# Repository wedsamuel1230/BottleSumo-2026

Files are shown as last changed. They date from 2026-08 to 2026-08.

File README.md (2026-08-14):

# BottleSumo 2026



Hardware, PCB, 3D model, and firmware files for the BottleSumo robot.

## Continuous build

Every pushed commit and pull request runs the Arduino CLI build workflow. The
workflow installs Arduino CLI 1.4.1 and Arduino-ESP32 3.3.8, then compiles the
firmware programs for the planned ESP32-S3-DEVKITC-1-N32R16 board:

```text
esp32:esp32:esp32s3-octal:FlashSize=32M
```

The badge above shows the latest GitHub Actions result. A passing compile only
proves that the sketch builds for the selected toolchain and memory interface;
it does not prove motor direction, sensor readings, FG pulse levels, or other
physical behavior.

The current hardware note assigns the two motor FG inputs to `GPIO9` and
`GPIO12`; the supplied motor reference states 9 FG square-wave pulses per
motor revolution. Electrical level and motor-to-pin assignment still require
bench verification.

The CI workflow installs the versioned candidate sensor libraries listed in
[`ci/arduino-libraries.txt`](ci/arduino-libraries.txt) before compiling every
Arduino sketch under `firmware/`. Arduino CLI resolves installed libraries when
it sees an `#include`, but it does not download an arbitrary missing library
from the registry automatically.

## Documentation

Use the [documentation hub](docs/README.md) to navigate the competition,
hardware, CI, and image references.

## Firmware

The current Arduino sketch is in
[`firmware/movement_test/movement_test.ino`](firmware/movement_test/movement_test.ino).
The pin audit in the board reference must be resolved before applying this
movement test to the assembled v2 PCB.

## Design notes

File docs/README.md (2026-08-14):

# BottleSumo documentation

Use this page as the documentation index. Documents are grouped by the task
they support, and image assets are kept in separate folders so the reference
pages stay easy to scan.

## Competition

- [2026 table-sumo rules](competition/table-sumo-rules-2026.md) - neutral project transcription of the attached Rev.0 rules document.
- [Sensor and strategy design v1](competition/table-sumo-design-v1.md) - research and design proposal with its approval boundary.
- [Design evidence ledger](competition/table-sumo-evidence-ledger.md) - source and evidence register for the design proposal.

## Hardware

- [ESP32-S3-DEVKITC-1-N32R16 pinout](hardware/esp32-s3-devkitc-1-n32r16-pinout.md) - board, GPIO, motor FG, LED, and firmware audit.
- [24GP-2430 motor reference](hardware/motor-24gp-2430-reference.md) - motor listing values, FG notes, and wiring cautions.

## CI and development

- [Arduino CI review](ci/arduino-ci-review.md) - validation gates and residual hardware risk.
- [Arduino sensor library matrix](ci/arduino-libraries.md) - pinned candidate library names and versions.

## Images

### Competition

- [Arena layout](images/competition/arena-layout.png)
- [Bottle dimensions](images/competition/bottle-dimensions.png)
- [Intentional-push ruling](images/competition/intentional-push-ruling.png)

### Motor

- [64:1 performance table](images/motor/motor-24gp-2430-64-to-1-specification.png)
- [Motor dimensions](images/motor/motor-24gp-2430-dimensions.png)
- [FG pulse description](images/motor/motor-24gp-2430-fg-pulse-description.png)
- [Motor wiring and FG](images/motor/motor-24gp-2430-wire-and-fg.png)

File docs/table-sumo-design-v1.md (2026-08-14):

# Table-Sumo Robot: Sensor and Strategy Design v1

Status: Phases 1-3 design review; no implementation authorization yet
Date: 2026-08-14
MCU: ESP32-S3, one controller
Baseline sensor set: 5 VL53L0X-class ToF heads, 4 analog QRE1113 heads

## Approval boundary

This document completes the research and design proposal only. It does not
authorize firmware, wiring changes, PCB changes, or a real-robot test. Phase 4
starts only after the operator approves the Phase 2 and Phase 3 decisions below.

The competition facts supplied in the task, and the repository rules digest in
`docs/rules.md`, are the controlling 2026 rules. External BottleSumo and sumo
sources are used for engineering context only; they do not override the local
rules.

## 1. Phase 1: research

### 1.1 Evidence boundary

The following are direct facts from the supplied rules, the repository, or the
listed device documentation:

- The senior arena can be two offset boards, so the walkable surface can be
  non-convex. The bottle lies somewhere on the joint line. [R1]
- A table edge is detected by the surface disappearing. A tape seam is a
  different event and is not a safe fixed threshold. [R1]
- VL53L0X devices power up at address `0x29`; XSHUT sequencing is required to
  assign addresses. [S2, S3]
- The VL53L0X carrier documentation lists a nominal 25 deg FoV, up to 2 m
  nominal range, 20 mA typical active current, 40 mA peak current, and 400 kHz
  I2C operation. Effective range depends on target and environment; use the
  task's approximately 1.2 m usable-indoor planning value until bench data
  replaces it. [R2, S3]
- The VL53L1X has a programmable ROI, typical 27 deg FoV, short mode around
  1.3 m, and up to 50 Hz short-mode sampling on the cited carrier. [S4]
- ESP32-S3 has two I2C interfaces, two 12-bit SAR ADCs, and ADC2 cannot be used
  with Wi-Fi simultaneously. GPIO0, GPIO3, GPIO45, and GPIO46 are strapping
  pins. [S5]
- The QRE1113 is a 940 nm IR LED plus phototransistor. Its datasheet example
  uses a 1 mm reflector distance; its response varies strongly with distance,
  reflectance, forward current, and ambient conditions. [S6]
- A prior BottleSumo ruleset explicitly defines intentional pushing as contact
  through a sensor-equipped side without contact with the other robot, and
  requires three-second survival. It is useful context, but the supplied 2026
  rules remain authoritative. [S7]

Engineering inferences are labeled as such below. No claim in this document is
physical proof for this robot.

### 1.2 ToF count trade-off: 3 vs 4 vs 5

For a 25 deg full FoV, the nominal transverse footprint at range `d` is:

`width(d) = 2 * d * tan(12.5 deg) = 0.443 * d`

Approximate footprint widths are 13.3 cm at 30 cm, 22.2 cm at 50 cm, 44.3 cm
at 1 m, and 53.2 cm at 1.2 m. Therefore one sensor cannot cover a 75 cm board
width at its practical VL53L0X range. The robot needs motion and a search
pattern; more sensors improve local angular coverage, not whole-arena vision.

| Count | Useful arrangement | Benefit | Cost and blind-zone risk |
|---|---|---|---|
| 3 | Front left, center, right | Lowest GPIO, power, and polling cost; enough for coarse centering | A narrow bottle can fall between beams; one failed head removes a large part of the front arc; little height/profile redundancy |
| 4 | Four contiguous front headings, or two front plus two rear | Better width estimate and some rear recovery awareness | No spare head for a second beam height; four one-shot readings increase stale-data age; two-front/two-rear weakens front lock-on |
| 5 | Three low front heads plus two mid-height outer heads | Contiguous front arc, fallen-bottle coverage, a second height for a tall opponent, and one-head fault tolerance | Five XSHUT lines, about 100 mA typical ToF current, more optical crosstalk testing, and a longer round-robin schedule |

Recommendation: use 5 heads if the actual ESP32-S3 board exposes the proposed
GPIOs and the mechanical bracket fits. A 4-head build is the fallback. Do not
choose 5 merely to claim long-range arena coverage; the search motion is still
mandatory.

Polling cost is dominated by the measurement budget, not the short I2C register
transactions. With a 33 ms budget and a conservative non-overlapping optical
schedule, one bus carrying `n` heads needs approximately `33*n` ms for a
complete fresh set, before bus overhead. A split of 3+2 heads therefore has a
worst bus schedule of about 99 ms, or roughly 10 Hz for the slow bus; a 2+2
four-head split is about 66 ms, or 15 Hz. A single global five-head optical
schedule is about 165 ms, or 6 Hz. The per-head measurement cadence can be
staggered, but the fusion layer must use the age of the oldest required sample,
not the nominal 30 Hz headline. At 400 kHz, the I2C start/status/range reads
are normally a few milliseconds or less and should be measured rather than
assumed. The two ESP32-S3 buses reduce transaction contention, but only a
physical crosstalk test permits overlapping exposures.

Each head adds one XSHUT GPIO and its power/ground branch. SDA and SCL remain
shared per bus. The incremental resource count is therefore approximately:

| Count | XSHUT GPIOs | I2C bus pins | Typical active ToF current | Conservative fresh-set schedule |
|---:|---:|---:|---:|---:|
| 3 | 3 | 2 or 4 | 60 mA | 66-99 ms depending on split |
| 4 | 4 | 4 if split 2+2 | 80 mA | about 66 ms |
| 5 | 5 | 4 if split 3+2 | 100 mA | about 99 ms split, 165 ms globally |

Coverage blind zones have two distinct causes. For heading separation `delta`
and a 25 deg FoV, the nominal angular gap is
`max(0, delta - 25 deg)`, with an approximate transverse gap
`2*d*tan(gap/2)` at range `d`. A 5 deg gap is about 4.4 cm at 0.5 m and
8.7 cm at 1 m; a 20 deg gap is about 17.6 cm and 35.3 cm. The proposed low
row uses 25 deg spacing, so it has no nominal angular gap, but a small bottle
can still be missed because of reflectance, target height, occlusion, and
non-overlap at the edges of real sensor response. Three heads have no spare
height or fault tolerance. Four heads can widen the same-height arc or add
rear awareness, but cannot provide both the low-row bottle coverage and the
mid-row opponent coverage without compromise. Five heads buy height/profile
redundancy and a wider arc at the cost of the schedule above.

### 1.3 ToF mounting geometry

The recommended front geometry is a 95 deg nominal front arc:

- `T0` low-left: optical center 70 mm above the table plane, 55 mm left of the
  robot centerline, yaw -25 deg from the marked front normal.
- `T1` low-center: optical center 70 mm above the table plane, centerline, yaw
  0 deg.
- `T2` low-right: optical center 70 mm above the table plane, 55 mm right of
  the centerline, yaw +25 deg.
- `T3` mid-left: optical center 130 mm above the table plane, 90 mm left of
  the centerline, yaw -35 deg.
- `T4` mid-right: optical center 130 mm above the table plane, 90 mm right of
  the centerline, yaw +35 deg.

The low trio covers the central arc with contiguous nominal 25 deg cones; real
module response may add or remove useful overlap. It is the primary detector
for a bottle lying on its side. The two outer heads extend
the arc and give a second height for an opponent with a taller front. The
low-center head must remain the authoritative approach head; the mid heads
must never be the only evidence used to attack a fallen bottle.

Mounting requirements:

- Measure every height from the laminate surface to the optical window center,
  not from the PCB or chassis.
- Keep the low beam at 65-75 mm. A horizontal bottle with an approximately
  100 mm high profile can intersect that beam; a 130 mm-only design could pass
  above it.
- Keep all heads square to their intended yaw. Do not use a common tilted
  bracket unless the actual pitch is measured and included in calibration.
- Use matte-black, non-glossy dividers or short hoods between adjacent windows.
  They must not intrude into the nominal 25 deg cones. Separate emitters
  physically and avoid pointing adjacent heads directly at each other.
- Do not start two overlapping optical exposures at the same time until a
  bench crosstalk test proves it safe. Two I2C buses reduce bus transaction
  contention; they do not automatically remove optical interference.
- Use the latest timestamp with each range. A stale or invalid range is not a
  target lock and cannot suppress the edge reflex.

VL53L1X upgrade decision: it is worth considering only if the operator has to
  buy new heads. Its longer range, ROI, and short/medium/long distance modes
  are useful for reducing false returns and narrowing a front beam, but the
  bottle is local and the arena still exceeds one sensor footprint. Replacing
  working VL53L0X heads is not the first priority. The upgrade also changes
  library/API and electrical validation risk. Baseline recommendation: keep
  VL53L0X-class heads for the first hardware gate; choose VL53L1X for a new
  build only if the price and driver support are acceptable and the ROI is
  needed after bench tests.

### 1.4 Bottle versus opponent

ToF-only discrimination is probabilistic, not a rule-grade identification:

- Motion: a bottle should remain fixed in world coordinates until pushed; an
  opponent can change range or bearing independently of the robot's commanded
  motion. This is useful only over several samples and is weak if the opponent
  pauses or the robot has no wheel feedback.
- Width: adjacent low heads returning similar distances suggest a broad robot;
  a single central return suggests a narrow bottle. The 25 deg cones overlap,
  so this is a relative feature, not a measured physical width.
- Distance stability: pause or creep for 200-500 ms. A static object produces a
  repeatable local geometry; a moving opponent produces inconsistent bearing or
  range. Wrinkles, a shiny object, and ToF noise can look similar.
- Height: the low row is intentionally biased toward the fallen bottle. The
  mid row can increase opponent confidence but cannot prove identity.

The classifier must expose `unknown`, `probable_bottle`, and
`probable_opponent`, not a binary fact. The push state requires front alignment
and contact evidence regardless of the label.

Optional cheap addition: one RGB/color sensor can help confirm an upright
bottle, but it is not required for the first build. Mount its optical center
at 99-100 mm above the table so the 3.8 cm band centered around the stated 8 cm
bottom offset is in view. Calibrate against the actual white wrapper and the
actual band during inspection; do not hardcode a color. Use a shroud and
controlled LED illumination. A sensor such as TCS34725 commonly uses address
`0x29`, so put it on a separate I2C bus or otherwise isolate it from the ToF
heads. An APDS-9960-class device avoids that address collision but still needs
ambient-light calibration. Color confirmation helps upright bottles; it is
unreliable when the bottle is horizontal or occluded and does not identify an
opponent. The more valuable optional addition for the intentional-push rule is
two low-profile front contact switches or a front contact strip.

### 1.5 QRE1113 layout and stopping distance

Use four analog sensors as four-corner edge sentinels, not as a line-following
array. The analog/digital choice matters:

- Analog/raw QRE output preserves the reflectance value. It permits separate
  table, tape, and void clusters, ambient compensation, margin measurement,
  and a seam probe. It costs four ADC inputs and ADC sampling time. Keep those
  inputs on ADC1, even if pit telemetry later uses Wi-Fi.
- A digital QRE module adds a comparator and gives a fast thresholded event. It
  is simpler and can feed an interrupt-capable digital input, but its
  threshold/hysteresis may be fixed or set by a potentiometer, and it cannot
  reliably distinguish a tape seam from a true void from one reading. It still
  needs a motion probe and on-site threshold check.

Recommendation: use the analog version if that is what the operator has. If
the operator has only a digital module, use it as a conservative two-state
edge candidate and disable seam tracking unless repeated seam probing proves
safe. Do not assume a module's silkscreen `D0` or `A0` polarity until it is
measured.

The edge path is "interrupt-class" in priority and behavior, not necessarily a
GPIO interrupt. For raw analog sensors, the safety task must sample at the
target rate and latch a hard candidate immediately; an ISR must not perform
ADC, I2C, or motor-library work. A digital comparator can additionally trigger
an ISR, but the ISR should only latch the event and let the safety task command
the motor override.

Layout:

- Front-left and front-right optical centers: 70 mm left/right of the robot
  centerline and 75 mm ahead of the front drive-wheel contact line.
- Rear-left and rear-right optical centers: 70 mm left/right of centerline and
  75 mm behind the rear drive-wheel contact line.
- Set the adjustable sensor-to-laminate gap to 2.0-3.0 mm. QRE1113's data sheet
  example is near 1 mm, but the competition requires at least 2 mm ground
  clearance except for permitted drive/essential structures. Actual gap and
  readings must be measured on the chosen module.
- Keep any body, wedge, or wheel structure no more than 10 mm ahead of the
  front sensor line if possible. The front optical line is the early-warning
  reference, not the bumper tip.

The braking calculation is:

`D_required = v * T_total + v^2 / (2 * a_effective) + D_margin`

where `T_total` includes ADC sampling, classification, task scheduling, and
motor command response. For illustration only, with `T_total = 20 ms`,
`a_effective = 1.5 m/s^2`, and `D_margin = 15 mm`:

- at 0.25 m/s, `D_required` is about 41 mm;
- at 0.35 m/s, `D_required` is about 63 mm.

The proposed 75 mm sensor lookahead leaves margin in that illustrative model.
It is not a speed approval: real attack speed is capped by the edge-reflex
milestone, and the operator will increase speed until the first controlled
failure. If the measured reaction plus braking time is 80 ms, the same values
become approximately 56 mm and 84 mm; the 0.35 m/s cap then fails the proposed
geometry and must be reduced or moved forward.

The seam classifier uses three calibrated clusters per sensor: table surface,
tape seam, and true void. A tape-like reading that returns to the table after
a short crossing is a `SEAM_CANDIDATE`, not a hard edge. A void-like reading
that is indistinguishable from the edge cluster is always treated
conservatively as an edge candidate. The robot probes by stopping, checking
rear surface presence, reversing only if rear-safe, and sampling again. If the
surface returns within the calibrated seam width, resume at a low seam speed;
otherwise retreat and turn away. No reflectance-only method can guarantee a
distinction when tape and void have identical optical readings, so this probe
is required and the residual ambiguity remains a risk.

### 1.6 Strategy research and design implications

The BottleSumo rules and prior event material consistently emphasize edge
detection, object detection, autonomous search, adaptation to unknown fields,
and three-second survival. A Pololu competition report describes four corner
reflectance sensors and front/side/rear proximity sensors, and also reports
that an unstructured random strategy spent too much time near the border. A
separate report describes roaming or spinning search patterns but also shows
that target angle and sensor height require tuning. These are reports from
other events, not proof of this arena. [S7, S8, S9]

The design therefore uses:

- interior-biased short chords and arcs, not a rectangle perimeter;
- continuous edge vigilance during every search and attack segment;
- an optional seam-track mode only after the seam signature is calibrated and
  repeatable; and
- front-square, straight pushing with no spin or side scrape while a bottle is
  in contact.

## 2. Phase 2: sensor and electrical architecture

### 2.1 Firmware platform decision

Recommendation: PlatformIO with the Arduino framework, using its ESP32-S3
FreeRTOS primitives and C++ libraries. This keeps the existing `.ino` movement
starting point and simplifies VL53L0X-class library integration while still
allowing pinned tasks, queues, watchdogs, ADC sampling, and direct GPIO control.
Do not run Wi-Fi during a match. Use USB serial for adjustment and optionally
enable a pit-only AP page later. Move to native ESP-IDF only if the selected
ToF driver or ADC timing cannot meet the measured gates.

### 2.2 I2C buses and XSHUT

The following is a proposed map for a bare ESP32-S3 or a board that exposes
these pins. It must be reconciled with the exact module schematic before wiring.

| Bus | SDA | SCL | Devices | Assigned addresses |
|---|---:|---:|---|---|
| I2C0 | GPIO8 | GPIO9 | T0, T1, T2 | 0x30, 0x31, 0x32 |
| I2C1 | GPIO10 | GPIO11 | T3, T4 | 0x33, 0x34 |

Proposed XSHUT lines:

| Head | Role | XSHUT GPIO | Bring-up order |
|---|---|---:|---:|
| T0 | low-left | GPIO12 | 1 |
| T1 | low-center | GPIO13 | 2 |
| T2 | low-right | GPIO16 | 3 |
| T3 | mid-left | GPIO18 | 4 |
| T4 | mid-right | GPIO21 | 5 |

Hold all XSHUT lines low with external pulldowns during reset if the carrier
does not already provide a reliable disabled state. Raise one head, confirm
`0x29`, assign its address, verify the new address, then continue. On every
power cycle the addresses must be assigned again. Use one effective I2C pull-up
pair per bus, normally 2.2-4.7 kohm to 3.3 V after checking and removing
duplicate carrier pull-ups. Keep the buses at 400 kHz only after signal
integrity is proven.

The two buses are separated by sensing group, not because they make five
optical exposures safe to run simultaneously. The initial schedule is
round-robin with non-overlapping exposures for adjacent optical cones. A bench
test may permit offset parallel bus operation; otherwise use a global optical
timeslot and accept the slower update rate.

### 2.3 ESP32-S3 pin budget

| GPIO | Proposed use | Direction/type | Decision and warning |
|---:|---|---|---|
| 1 | Left PWM | output | Existing movement firmware contract; also ADC1-capable but not used as analog |
| 2 | Left direction | output | Existing movement firmware contract; also ADC1-capable but not used as analog |
| 3 | unused | - | Avoid: strapping/JTAG selection pin |
| 4 | QRE front-left analog | ADC1 input | Preferred analog input |
| 5 | QRE front-right analog | ADC1 input | Preferred analog input |
| 6 | QRE rear-left analog | ADC1 input | Preferred analog input |
| 7 | QRE rear-right analog | ADC1 input | Preferred analog input |
| 8 | I2C0 SDA | bidirectional | Digital bus |
| 9 | I2C0 SCL | output | Digital bus |
| 10 | I2C1 SDA | bidirectional | Digital bus |
| 11 | I2C1 SCL | output | Digital bus |
| 12 | T0 XSHUT | output | Add pulldown if needed |
| 13 | T1 XSHUT | output | Add pulldown if needed |
| 14 | Right direction | output | Existing movement firmware contract; do not use for QRE analog |
| 15 | Right PWM | output | Existing movement firmware contract; board may use alternate 32 kHz function |
| 16 | T2 XSHUT | output | Verify module exposes it and reset behavior is acceptable |
| 17 | status LED | output | Existing movement firmware contract; optional only |
| 18 | T3 XSHUT | output | Digital GPIO |
| 19-20 | reserved | - | USB Serial/JTAG/USB pins; do not repurpose casually |
| 21 | T4 XSHUT | output | Digital GPIO |
| 22-32 | reserved | - | Module flash/PSRAM and package-dependent pins; do not assume exposed |
| 33-37 | reserved | - | Can conflict with flash/PSRAM on some variants |
| 38 | remote-start input | input | Proposed active-low input; verify board breakout |
| 39-42 | reserved | - | JTAG-related pins; do not use in baseline |
| 43-44 | reserved | - | UART0 default pins |
| 45-46 | unused | - | Avoid: strapping pins |

Optional front contact inputs are not in the baseline map. If selected, use
GPIO39 and GPIO40 only after verifying the exact board and deliberately
disabling/releasing JTAG; otherwise revise the map around actually exposed
spare pins. Do not silently use a different board pin. A common motor-driver
enable/kill line is desirable for hardware edge shutdown but is also
board/driver-dependent; it must be added to the reviewed map before wiring.

The proposed map is a pin budget, not a claim that the current PCB routes these
nets. The current repository has movement firmware on GPIO1/2/15/14 and CAD
assets for the sensor families, but no validated ESP32-S3 sensor netlist.

### 2.4 Power budget and brownout controls

| Load | Design estimate | Evidence/status |
|---|---:|---|
| ESP32-S3 plus 3.3 V logic | 80-180 mA typical, higher transient | Engineering budget; measure on the selected module |
| Five VL53L0X carriers | 100 mA typical, up to about 200 mA if all peak together | Carrier specification lists 20 mA typical and 40 mA peak per head [S3] |
| Four QRE emitters | 40-80 mA at a deliberately chosen 10-20 mA each | Engineering budget; QRE maximum is not a recommended operating point [S6] |
| Motor-driver logic, LED, pull-ups | 20-60 mA | Measure selected parts |
| Optional color sensor and illuminator | 5-50 mA | Depends on module and LED duty cycle |
| Logic-rail design target | 300-450 mA typical, 700 mA transient allowance | Choose a regulated 3.3 V rail rated at least 1 A continuous |
| Motors | dominant load; stall current is not supplied here | Driver, battery, wiring, fuse, and brownout test required |

Use a separate regulated logic rail from the motor rail, common ground at one
controlled star point, short sensor wiring, local 0.1 uF bypass capacitors, and
at least 470 uF bulk capacitance at the ESP32/ToF rail. A 2S pack is a possible
starting point because its 8.4 V full-charge voltage is below 14 V, but the
actual battery and motor-driver ratings must be checked and measured. The
current battery model is not proof of the assembled battery voltage.

Brownout mitigations are mandatory design requirements: motor current must not
share a weak MCU regulator, motor wiring must not run through the sensor rail,
the regulator must tolerate motor-induced input transients, and the first
full-speed test must log resets or brownouts. Wi-Fi is off in a match, but all
analog QRE inputs remain on ADC1 so pit telemetry cannot create a hidden ADC2
failure.

### 2.5 Decision latency

Target rates:

- QRE ADC scan: 200 Hz per channel; two consecutive void-like samples for a
  hard candidate; safety task and motor override at 100 Hz.
- ToF: 33 ms timing budget initially, per-head timestamped round-robin; target
  fresh data age below 110 ms with two bus schedules. If optical crosstalk
  forces one global schedule, the conservative bound is about 170-180 ms for
  the five-head cycle.
- Strategy/fusion task: 20 Hz or faster, never allowed to own the motor safety
  override.

Worst-case design bounds:

| Path | Bound | Consequence |
|---|---:|---|
| QRE hard edge candidate to motor override | 20-25 ms target | Edge reflex is independent of ToF, serial, and Wi-Fi |
| Seam probe classification | 50-120 ms | Robot must be slow during seam handling and keep rear QRE armed |
| Fresh ToF reading to fusion decision | 110 ms nominal; 180 ms conservative | Do not use ToF as edge protection; cap approach speed and reject stale data |
| Serial/AP adjustment | unbounded relative to match loop | Disabled or isolated from safety task during a round |

These are acceptance targets, not measurements. Phase 4 must replace them with
captured timestamps from the actual board.

### 2.6 Rules compliance checklist

| Rule constraint | Design response | Status |
|---|---|---|
| One of max two controllers | One ESP32-S3 | By design; inspect actual hardware |
| Max three motors | Two differential motors baseline; no mechanism motor | By design |
| Sensors unlimited and harmless | ToF Class 1 carriers, low-current QRE, optional passive/contact sensors | Verify selected modules |
| <=30 cm diameter/height | Keep sensor brackets inside the static envelope | Must measure assembled robot |
| <=35 cm expanded | No expansion mechanism in baseline | Must measure if any mechanism is added |
| <=1 kg | Five heads add little mass, but battery/chassis dominate | Must weigh assembled robot |
| >=2 mm ground clearance | QRE bracket target 2.0-3.0 mm; no lower structure | Must measure and calibrate |
| Battery <14 V | Candidate 2S supply is below limit; actual pack is not yet confirmed | Must measure full-charge voltage |
| No suction/sticky traction/sharp parts | Normal wheels and a passive rounded front face | Inspect finished chassis |
| Autonomous after remote start | GPIO start trigger; no wireless control in a round | Validate start and remote placement rule |

Third motor decision: do not add one in the baseline. A passive rounded bottle
guide inside the static envelope is lower risk than an active flap. An active
flap adds weight, failure modes, expansion/compliance questions, and could make
side contact look unintentional. Revisit a third motor only after a mechanical
review proves it preserves continuous marked-front contact and does not change
the ruling geometry.

## 3. Phase 3: strategy and behavior architecture

### 3.1 Priority contract

Priority is strict, highest first:

1. Edge safety and edge/seam probe.
2. Survival timer after a judged win condition is inferred.
3. Front-contact and alignment integrity during a push.
4. Opponent/bottle target lock and reacquisition.
5. Recovery from push, seam, wrinkle, or stall.
6. Search and anti-draw progress.
7. Logging, serial, and pit configuration.

The strategy task proposes a motion. The safety task owns the final motor
output. A ToF timeout, serial command, color mismatch, or logging overload can
never block the QRE safety path.

### 3.2 State machine

```mermaid
stateDiagram-v2
    [*] --> ARM_WAIT
    ARM_WAIT --> SEARCH: remote start and self-check pass
    ARM_WAIT --> EDGE_REFLEX: QRE hard candidate

    SEARCH --> SEAM_TRACK: calibrated seam candidate persists
    SEARCH --> TARGET_LOCK: adjacent ToF lock candidate
    SEARCH --> RECOVERY: no motion evidence or obstruction
    SEARCH --> EDGE_REFLEX: any hard QRE candidate

    SEAM_TRACK --> TARGET_LOCK: bottle/opponent candidate on seam
    SEAM_TRACK --> SEARCH: seam lost or seam profile invalid
    SEAM_TRACK --> EDGE_REFLEX: void-like QRE candidate

    TARGET_LOCK --> SQUARE_UP: center error and range stable
    TARGET_LOCK --> REACQUIRE: lock lost or data stale
    TARGET_LOCK --> EDGE_REFLEX: any hard QRE candidate
    REACQUIRE --> SEARCH: reacquire timeout
    REACQUIRE --> TARGET_LOCK: lock restored

    SQUARE_UP --> PUSH: front aligned and front contact confirmed
    SQUARE_UP --> TARGET_LOCK: alignment timeout or target moves
    SQUARE_UP --> ABORT_PUSH: side contact, opposing contact, or ambiguity
    SQUARE_UP --> EDGE_REFLEX: any hard QRE candidate

    PUSH --> SURVIVE: bottle/opponent leaves and front contact releases
    PUSH --> ABORT_PUSH: front alignment/contact lost
    PUSH --> EDGE_REFLEX: any hard QRE candidate
    ABORT_PUSH --> SURVIVE: unsafe edge or opponent event requires retreat
    ABORT_PUSH --> TARGET_LOCK: target remains and front can be restored
    ABORT_PUSH --> SEARCH: target lost

    EDGE_REFLEX --> SEAM_TRACK: probe confirms calibrated seam and rear-safe
    EDGE_REFLEX --> SEARCH: retreat and turn complete
    EDGE_REFLEX --> SURVIVE: push was active and retreat is required

    RECOVERY --> SEARCH: motion restored
    RECOVERY --> EDGE_REFLEX: recovery reveals edge
    RECOVERY --> SURVIVE: unsafe geometry after push

    SURVIVE --> HOLD_SAFE: three-second survival timer complete
    SURVIVE --> EDGE_REFLEX: retreat edge candidate
    HOLD_SAFE --> [*]
```

### 3.3 State conditions

`ARM_WAIT`: hold motors disabled, assign all ToF addresses, check plausible
QRE values, and wait for the remote-start trigger. There is no automatic
wireless control path after start.

`EDGE_REFLEX`: on a hard void candidate, immediately stop forward drive and
command the safest reverse/turn based on which front/rear sensors still see
surface. This path does not wait for ToF, classification, or serial. If the
reading is seam-like or ambiguous, stop and perform the seam probe. If the
reading is identical to calibrated void, remain conservative until surface is
proven. A single-sensor mid-straight event is not ignored: it gets the same
protective probe.

`SEARCH`: use short, interior-biased motion primitives: forward chord 0.4-0.8
s, shallow arc, 35-55 deg pivot, then another chord. Alternate turn direction
and insert a slow 90-120 deg scan every 1-2 s. Never follow a presumed outer
rectangle. Every primitive is interruptible by QRE. If the seam signature is
stable across two crossings, enable `SEAM_TRACK`; otherwise use the general
search. A seam track is a conditional advantage, not a prerequisite for finding
the bottle.

`SEAM_TRACK`: keep the seam candidate under the front sensor pair or selected
line sensor geometry at low speed. If the four-corner QRE layout cannot see the
seam consistently because the tape falls between sensors, abandon tracking and
return to short-chord search. A void-like seam still invokes the probe.

`TARGET_LOCK`: accept a target only from fresh, plausible ToF readings. Prefer
the low row. Require the center head plus an adjacent head, or two adjacent
heads with consistent range, for a stable lock. Maintain a 200-500 ms motion
or creep test before classification. Treat the result as probable bottle,
probable opponent, or unknown. Loss of a head or stale data forces
`REACQUIRE`, never blind pushing.

`SQUARE_UP`: steer until the marked front normal is aligned: left/right range
error is small and stable, center range is plausible, and the front contact
switches (if installed) agree. Do not enter a bottle push from a side sensor or
from a spinning maneuver. If another robot is touching the target or contact
status is ambiguous, abort the bottle push and continue one-on-one sumo
behavior only through the marked front.

`PUSH`: creep into contact, maintain continuous front-face contact, and use
only small differential corrections that preserve the front normal. No spin,
side swipe, or rear contact is permitted while the bottle is in the push path.
The QRE safety path remains active throughout. If alignment, front contact, or
opponent-contact exclusion is lost, stop and abort instead of trying to save a
bad push with a turn.

`SURVIVE`: when the target leaves or an opponent is inferred to have fallen,
brake, reverse along the last safe push axis, and turn toward the side with the
most surface evidence. Keep all four QRE sensors live. Start a three-second
timer only after the robot is stable and on-surface; do not treat the timer as
an afterthought. Hold in a safe interior posture until the timer completes.

`RECOVERY`: detect a likely wedge, wrinkle, seam trap, or push by a motor
command with no change in ToF/QRE evidence. Use a short reverse, then a capped
pivot; if the same snapshot persists, change search direction and speed. A
motor-current sensor and wheel encoders would make this reliable, but are not
assumed in the first sensor set. Without them, the recovery signal is a
bounded heuristic and must be tested.

`ANTI_DRAW`: maintain a progress ledger. A progress event is a measured wheel
motion if encoders exist, a meaningful ToF range/bearing change, a completed
search primitive, a seam crossing, or a target/contact event. Never allow a
quiet wait longer than 250 ms outside safety handling. At 10 s without target
progress, change search pattern; at 20 s, execute recovery; at 25 s, force a
visible short-chord/scan cycle. These internal thresholds are deliberately
earlier than the 30 s draw condition.

### 3.4 Task split and rates

Pin the safety/control task to one core and the sensing/strategy tasks to the
other:

- Core 0, highest priority: 200 Hz QRE ADC scan, edge/seam candidate latch,
  100 Hz motor safety/control, start/stop latch, watchdog, and optional battery
  fault. No I2C, Wi-Fi, or blocking serial.
- Core 1: I2C0 and I2C1 ToF schedules, optional color sensor, target fusion,
  state machine, search primitive generation, and bounded logging.
- Inter-core interface: timestamped immutable sensor snapshots and a single
  motion proposal queue. Core 0 can discard or override every proposal.

The 100 Hz control rate gives a 10 ms actuation period, while 200 Hz QRE
sampling supplies two samples in roughly 10 ms. ToF is intentionally slower
and timestamped; it is not allowed to define edge safety. If the actual ADC or
motor driver cannot meet the 20-25 ms edge bound, the maximum speed must be
reduced before target testing.

### 3.5 Thirty-second between-round adjustment playbook

Primary interface: USB serial at 115200 baud while the robot is in pit/setup
mode. Optional pit-only Wi-Fi AP may expose the same parameter set, but it is
disabled before a round. A physical button can select one of two saved profiles
if serial access is unreliable; it should not be the only calibration path.

Expose only bounded parameters:

- four QRE table, seam, and void cluster centers plus safety margins;
- seam probe distance/time and `SEAM_TRACK_ON/OFF`;
- ToF minimum/maximum usable range, stale-data timeout, lock confidence, and
  adjacent-hit requirement;
- search mode: `SHORT_CHORD`, `SEAM_SEEK`, or `CONSERVATIVE_SCAN`;
- speed caps for search, square-up, push, and retreat;
- differential correction gain and maximum yaw correction during push;
- edge retreat distance, pivot direction policy, and three-second hold mode.

Suggested 30-second sequence:

1. 0-5 s: power, check no reset, clean all optical windows, verify start mode.
2. 5-12 s: sample the actual table, a representative tape seam, and an
   over-edge void. Store readings and margins; never type a universal threshold.
3. 12-17 s: place a bottle/opponent in front, verify all five addresses and
   that no head reports stale/invalid data.
4. 17-22 s: choose seam tracking only if the seam cluster is separated and
   repeated; otherwise choose short-chord search.
5. 22-27 s: set the already-qualified speed profile and push alignment mode;
   do not increase speed beyond the Phase 4 measured cap.
6. 27-30 s: confirm remote-start armed, wireless off, and motors safe until
   the official trigger.

## Match-day checklist

### Physical and rules check

- Measure static diameter, height, expanded size if any part moves, weight, and
  minimum ground clearance.
- Measure full-charge battery voltage and verify the declaration requirement
  for the actual pack.
- Confirm only one controller and two motors are installed in the baseline.
- Confirm the marked front face is the sensor-equipped push face; remove or
  round anything that could create side-contact ambiguity.
- Confirm the remote trigger is the only external control and that the remote
  leaves the table area as required.

### Actual-board calibration

- Sample all four QREs over the actual laminate at several points and with the
  robot stationary and moving slowly.
- Sample the actual seam/tape at multiple orientations and widths.
- Sample each QRE over the true table edge with the actual support height and
  background visible.
- Store table, seam, and void distributions, not one raw threshold. If seam
  and void overlap, select conservative probe behavior and disable seam track.
- Move across the seam at slow speed and verify readings return to table
  values. A seam that does not return is an unresolved safety risk.

### ToF and optional band check

- Confirm each head initializes to its assigned address after a power cycle.
- Place a white target at 0.2, 0.5, and 1.0 m and check timestamped readings.
- Run the crosstalk test with adjacent heads individually enabled and with the
  intended staggered schedule.
- Sweep an upright bottle and a horizontal bottle through each low-head cone.
- If the color sensor is installed, sample white wrapper and band under actual
  lighting, store normalized color clusters, and test both upright and lying
  orientations. A failed band classifier must not disable ToF search.

### Starting-pose decision guide

- Identify which direction is clearly interior from the revealed table layout;
  do not infer a rectangle from one board.
- If the seam signature is strong and the seam is reachable without crossing a
  void-like reading, select `SEAM_SEEK`.
- If the seam is weak, narrow, or void-like, select `SHORT_CHORD` and use seam
  crossings only as progress events.
- If a front QRE is near an edge at start, perform a short protective pivot
  before any forward burst.
- If the starting heading points into interior space with all front QREs on
  table, use the low-speed forward chord; otherwise begin with a scan/pivot.
- Starting orientation is unknown until the event; no fixed heading or board
  corner is encoded in the design.

## Risk register

| Risk | Failure mode | Mitigation and gate |
|---|---|---|
| Seam false-edge | Tape looks like a void and causes repeated aborts or, if ignored, an edge fall | Three-cluster calibration, conservative stop/probe, rear-surface check, seam-track disable when clusters overlap; test on actual tape |
| Fallen bottle below beam height | A high-only ToF arrangement misses the horizontal bottle | Low row at 65-75 mm, low-center authority, explicit upright and horizontal sweep milestone |
| Unintentional-push ruling | Side contact, spin, or contact with the opponent makes a bottle fall without a clean marked-front push | Square-up state, front contact confirmation, no spin during push, abort on alignment/opponent ambiguity, straight retreat after release |
| Non-convex edge surprise | A concave offset-board edge appears mid-chord and a rectangle-based search drives over it | No perimeter assumption, short interruptible primitives, four-corner continuous QRE vigilance, edge probe on any sensor |
| Draw by stagnation | Search, recovery, or seam tracking appears idle for 30 s | Progress ledger, 10/20/25 s strategy changes, no long waits, visible short-chord fallback, speed and recovery tests |

Additional engineering risks remain: ToF optical crosstalk, module pull-up
overloading, motor brownout, unverified ESP32-S3 board pin exposure, and QRE
module variant mismatch. These are explicit Phase 4 gates rather than silently
accepted assumptions.

## Phase 4 gate and operator protocol

The following milestones are intentionally not executed in this turn:

1. Bench address/range dump for all ToF heads.
2. QRE table/edge/tape measurement supplied by the operator.
3. Edge-only speed ramp, with the first failure speed recorded as a cap.
4. Upright and lying bottle ToF sweep.
5. Front-square intentional push test.
6. Staged state-machine tests and a complete two-minute endurance round.

For each milestone I will provide one concrete procedure and a stop condition.
You will run it on the real robot and report measured output. I will not infer
hardware behavior from a compile, a serial banner, or a plausible wiring plan.
There are at most three repair cycles per milestone; after the third failure,
the milestone stops with hypotheses and evidence recorded.

Approval requested before Phase 4:

- Approve or reject the five-head geometry and 4-head fallback.
- Confirm the exact VL53L0X/VL53L1X carrier and QRE1113 analog/digital variant.
- Confirm the exact ESP32-S3 module/dev-board pin exposure before wiring.
- Approve Arduino/PlatformIO with FreeRTOS task split, or request ESP-IDF.
- Decide whether to add front contact switches and/or the optional color sensor.
- Approve the no-third-motor baseline.

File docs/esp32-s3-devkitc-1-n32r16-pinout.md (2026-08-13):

# ESP32-S3-DEVKITC-1-N32R16 project reference

This document is the working pin and hardware reference for the BottleSumo
controller.

## Board identity

- **Planned physical board:** `ESP32-S3-DEVKITC-1-N32R16`
- **Arduino CLI profile:** `esp32:esp32:esp32s3-octal:FlashSize=32M`
- **Arduino-ESP32 core tested:** `3.3.8`
- **Memory meaning:** `N32R16` denotes 32 MB flash and 16 MB octal PSRAM.
- **Attached PCB schematic label:** `ESP32-S3-DEVKITC-1-N8R8`

The schematic and PCB preview currently carry the older `N8R8` library label.
The production board choice is `N32R16`; the memory variant does not change the
GPIO numbering used by the project. The CAD label should be updated in a future
design revision, but the existing design files are intentionally not rewritten
by the CI setup change.

Source design files:

- [v2 schematic source](../PCB/v2/Bottlesumo-v2.fsch)
- [v2 PCB source](../PCB/v2/Bottlesumo-v2.fbrd)
- [v2 schematic preview](../PCB/v2/SCH.png)
- [v2 PCB preview](../PCB/v2/PCB.png)

## Project signal map

The table below combines the v2 schematic net names with the motor FG detail
provided for this build.

| GPIO | Project signal | Direction or use | Source / note |
| ---: | --- | --- | --- |
| 1 | `IR1_OUT` | Input | QRE1113 sensor 1 output in schematic |
| 2 | `IR2_OUT` | Input | QRE1113 sensor 2 output in schematic |
| 4 | `IR3_OUT` | Input | QRE1113 sensor 3 output in schematic |
| 5 | `IR4_OUT` | Input | QRE1113 sensor 4 output in schematic |
| 6 | `XSHUT1` | Output | VL53L0X shutdown control, schematic label |
| 7 | `XSHUT2` | Output | VL53L0X shutdown control, schematic label |
| 9 | `MOTOR1_FG` (working assignment) | Input / pulse counter | User note: FG input; 9 square-wave pulses per motor revolution; verify motor loom assignment |
| 10 | `PWM1` | PWM output | Motor 1 speed-control net in v2 schematic |
| 11 | `DIR1` | Digital output | Motor 1 direction net in v2 schematic |
| 12 | `MOTOR2_FG` (working assignment) | Input / pulse counter | User note: FG input; 9 square-wave pulses per motor revolution; verify motor loom assignment |
| 13 | `PWM2` | PWM output | Motor 2 speed-control net in v2 schematic |
| 14 | `DIR2` | Digital output | Motor 2 direction net in v2 schematic |
| 15 | `XSHUT3` | Output | VL53L0X shutdown control, schematic label |
| 16 | `SCL` | I2C clock | v2 schematic; pass explicitly to `Wire.begin()` |
| 17 | `SDA` | I2C data | v2 schematic; pass explicitly to `Wire.begin()` |
| 19 | `USB_D-` | USB data | ESP32-S3 USB function |
| 20 | `USB_D+` | USB data | ESP32-S3 USB function |
| 43 | `U0TXD` | UART transmit | Board UART signal |
| 44 | `U0RXD` | UART receive | Board UART signal |

Power and ground connections are shown in the schematic and must be checked
against the assembled board before power is applied. The motor supply is a
separate 12 V rail in the design; do not connect it to an ESP32 GPIO or 3V3
pin.

## Current firmware pin audit

The existing movement sketch is preserved for CI compilation, but its constants
do not match the v2 schematic signal map:

| Sketch constant | Current GPIO | v2 schematic / planned GPIO | Concern |
| --- | ---: | ---: | --- |
| `LPWM` | 1 | 10 | GPIO1 is `IR1_OUT` in the schematic |
| `LDIR` | 2 | 11 | GPIO2 is `IR2_OUT` in the schematic |
| `RPWM` | 15 | 13 | GPIO15 is `XSHUT3` in the schematic |
| `RDIR` | 14 | 14 | Matches `DIR2` |
| `LED1` | 17 | 17 | GPIO17 is `SDA` in the schematic |
| FG inputs | Not implemented | 9 and 12 | Add pulse capture only after electrical-level validation |

Do not use the current movement sketch for a powered motor test until this
audit is resolved in firmware and reviewed against the physical PCB. CI is a
compile gate, not a hardware approval gate.

## I2C note

The schematic assigns `SCL=GPIO16` and `SDA=GPIO17`. Arduino's generic ESP32-S3
defaults are different, so sensor firmware should set the bus explicitly, for
example:

```cpp
Wire.begin(17, 16);  // SDA, SCL from the BottleSumo v2 schematic
```

The three VL53L0X devices share the I2C bus and use separate XSHUT controls for
address assignment. The exact physical sensor order must follow the labels on
the assembled PCB.

## FG pulse reference

The supplied motor image states that one motor revolution produces **9
square-wave FG pulses**. It does not establish whether that count is referenced
to the internal motor shaft or the geared output shaft, so treat the shaft
location as an open hardware question. For a measured FG frequency, use the
confirmed pulse count and shaft reference:

```text
output_shaft_rpm = fg_frequency_hz * 60 / 9
```

The selected 64:1, 12 V listing gives approximately 75 RPM rated speed and
94 RPM no-load speed. Those values correspond to approximately 11.25 Hz and
14.10 Hz at the FG output if the 9-pulse specification applies at the geared
output shaft.

Before connecting either FG line to GPIO9 or GPIO12:

1. Confirm the motor wire identity and output electrical level from the actual
   motor documentation or a current-limited bench measurement.
2. Confirm whether an external pull-up is required and pull up only to an
   ESP32-safe voltage.
3. Never apply the motor's 12 V rail to an ESP32 GPIO.
4. Validate pulse polarity, frequency, and duty cycle with the motor unloaded
   before enabling closed-loop control.

The motor listing also specifies a 15-25 kHz PWM speed-control input. The
current `analogWrite()` sketch is not evidence that this frequency is configured
and should be replaced or configured deliberately during the motor-control
firmware update.

## Verification boundaries

Verified by repository/toolchain inspection:

- The current sketch compiles with the Arduino-ESP32 3.3.8 core for the 32 MB
  flash and OPI PSRAM configuration.
- The v2 schematic contains the project GPIO nets listed above.

Still requiring hardware evidence:

- The exact purchased board marking and memory population.
- Motor wire colors and FG voltage level.
- Motor direction polarity and PWM input behavior.
- Sensor startup, XSHUT ordering, and I2C readings.

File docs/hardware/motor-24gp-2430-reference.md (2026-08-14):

# MY24GP-2430 motor reference

This note records the useful values visible in the supplied Taobao listing for
the selected motor. It is a purchase-listing reference, not a substitute for a
manufacturer datasheet or a bench measurement.

## Selected variant

- Motor family: `MY24GP-2430` planetary geared motor
- Selected reduction ratio in the supplied image: **64:1**
- Nominal supply table recorded: **12 V**
- Motor-before-reduction speed shown: **6000 RPM**
- Gearbox output shaft: 6 mm diameter, according to the supplied dimension image
- Motor body diameter: approximately 24 mm, according to the supplied image

## 12 V, 64:1 listing values

| Parameter | Listing value |
| --- | ---: |
| No-load output speed | 94 RPM |
| Rated output speed | 75 RPM |
| Rated torque | 1.5 kgf.cm |
| Rated current | 0.35 A |
| Rated input power | 2.8 W |
| Limit torque | 3.6 kgf.cm |
| Limit current | 1.4 A |
| Limit input power | 4.5 W |

The 94 RPM no-load value is consistent with approximately `6000 / 64 = 93.75`
RPM before accounting for gearbox losses and listing rounding.

## Motor control and FG

The supplied motor wiring image states:

- PWM speed-control input: 15-25 kHz
- FG output: for external speed measurement
- FG pulse count: 9 square-wave pulses per motor revolution, according to the
  supplied image; confirm whether the seller means the internal or geared
  output shaft
- Direction and PWM are separate control lines in the listing

The image does not establish the ESP32-safe FG voltage, pull-up arrangement,
wire colors, or direction polarity. Verify those on the purchased motor before
connecting it to the controller. See the [ESP32 project pinout reference](esp32-s3-devkitc-1-n32r16-pinout.md)
for the assigned `GPIO9` and `GPIO12` inputs.

For speed measurement:

```text
output_shaft_rpm = fg_frequency_hz * 60 / 9
```

Expected FG frequencies from the 12 V, 64:1 listing are approximately if the
9-pulse count applies at the geared output shaft:

| Operating point | Output speed | Expected FG frequency |
| --- | ---: | ---: |
| Rated | 75 RPM | 11.25 Hz |
| No-load | 94 RPM | 14.10 Hz |

## Mechanical notes

The supplied dimension drawings show a 24 mm body, a 6 mm output shaft, and a
mounting bracket with a 31 mm upright dimension and 33.5 mm base length. Confirm
the selected gearbox ratio and bracket orientation before finalizing the 3D
model mounting holes.

## Source images

The source images supplied for this note are kept beside it:

- [Motor wiring and FG description](../images/motor/motor-24gp-2430-wire-and-fg.png)
- [FG pulse-count note](../images/motor/motor-24gp-2430-fg-pulse-description.png)
- [Motor dimensions](../images/motor/motor-24gp-2430-dimensions.png)
- [64:1 performance table](../images/motor/motor-24gp-2430-64-to-1-specification.png)

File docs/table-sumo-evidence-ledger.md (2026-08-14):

# Table-Sumo Design Evidence Ledger

Date: 2026-08-14
Purpose: provenance for `docs/table-sumo-design-v1.md`

## Source register

| ID | Source | Evidence tier | Used for |
|---|---|---|---|
| R1 | Repository rules digest: [docs/rules.md](rules.md) | Local project rule baseline supplied with checkout | Arena, bottle, intentional push, size, weight, battery, autonomy, three-second survival, and unknown configuration |
| R2 | User task, "Competition Context (official 2026 rules)" | Authoritative user-provided rule contract | 2026 facts that must override older external rules |
| S1 | ST, VL53L0X product/datasheet landing material: https://www.st.com/en/imaging-and-photonics-solutions/vl53l0x.html | Primary vendor | VL53L0X family and official API context |
| S2 | ST, VL53L0X datasheet: https://www.st.com/resource/en/datasheet/vl53l0x.pdf | Primary vendor | Device capabilities and known 0x29/XSHUT facts; the task supplied the exact multi-device facts |
| S3 | Pololu, VL53L0X carrier: https://www.pololu.com/product/2490 | Vendor carrier documentation | 25 deg FoV, 2 m nominal maximum, 20 mA typical, 40 mA peak, 400 kHz, XSHUT behavior, 0x29 default, effective-range caveats |
| S4 | Pololu, VL53L1X carrier: https://www.pololu.com/product/3415 | Vendor carrier documentation | 27 deg FoV, ROI, short-mode range/update-rate trade-off, 400 cm favorable-condition claim, carrier electrical notes |
| S5 | Espressif, ESP32-S3 datasheet v2.2: https://documentation.espressif.com/esp32-s3_datasheet_en.pdf | Primary vendor; downloaded and text-checked | Two I2C interfaces, ADC1/ADC2 channels, ADC2/Wi-Fi restriction, strapping pins, GPIO restrictions, 500 mA single-supply recommendation |
| S6 | onsemi QRE1113/QRE1113GR datasheet copy: https://docs.rs-online.com/9e66/A700000007797649.pdf | Component vendor datasheet copy; downloaded and text-checked | 940 nm emitter, phototransistor output, 1 mm example, optical/electrical limits, ambient/distance sensitivity |
| S7 | Robofest BottleSumo 2024 rules: https://www.robofest.net/images/2324/BottleSumo2024_V1.pdf | Related event rules; not controlling | Search/edge/unknown-field emphasis, front sensor side, intentional/unintentional push wording, three-second survival, no-progress condition |
| S8 | Pololu, Patrick's mini-sumo robot: https://www.pololu.com/blog/540/patricks-mini-sumo-robot-covert-ops | Competition report/anecdote | Four corner reflectance layout and multi-direction proximity sensor precedent; reported limitations |
| S9 | Pololu, Brandon's mini-sumo robot: https://www.pololu.com/blog/547/brandons-mini-sumo-robot-black-mamba | Competition report/anecdote | Roaming/spinning search and target-angle/sensor-height trade-offs |
| S10 | Pololu, Applied Robotics with the SumoBot: https://www.pololu.com/file/0J209/AppliedSumo-v1.0.pdf | Educational guide | Search-pattern, edge-avoidance, sensor timing, calibration, and strategy-change context |

## Fact versus inference ledger

### Directly supported facts

- `docs/rules.md` states the two-board offset/non-convex possibility, joint-line
  bottle placement, light-colored table, tape seam, unknown support height,
  bottle dimensions, intentional front contact, three-second survival, and
  hardware limits. [R1, R2]
- The VL53L0X carrier page states 25 deg FoV, nominal 2 m range, 20 mA typical
  active-ranging current, 40 mA peak, 400 kHz I2C, active-low XSHUT, and default
  address `0x29`. [S3]
- The VL53L1X carrier page states a programmable ROI, 27 deg typical FoV,
  short mode around 130 cm and 50 Hz maximum, and medium/long mode trade-offs.
  [S4]
- The ESP32-S3 datasheet states two I2C interfaces, ADC1 and ADC2 channels,
  ADC2/Wi-Fi incompatibility, and GPIO0/3/45/46 strapping roles. It also
  recommends at least 500 mA if a single supply powers the chip. [S5]
- The QRE1113 datasheet states a 940 nm peak emitter, phototransistor output,
  a 1 mm white-paper/mirror example, and response characteristics that are
  dependent on distance, current, and ambient temperature. [S6]
- Related BottleSumo/sumo sources emphasize edge detection, object detection,
  autonomous search, unknown field conditions, and post-push survival. [S7,
  S10]

### Engineering inferences

- Five ToF heads are a good local front-arc compromise because the 25 deg
  footprint is narrow relative to a 75 cm board and a second low/mid geometry
  reduces profile blind spots. This is a design judgment, not a vendor claim.
- A 70 mm low optical center is a practical compromise between seeing a
  roughly 100 mm horizontal bottle profile and detecting ordinary opponent
  chassis structure. It must be confirmed with the actual bottle and robot.
- A 75 mm QRE lookahead can support the illustrative 0.25-0.35 m/s speeds only
  under the stated braking assumptions. The actual attack cap must come from
  the edge-speed failure test.
- ToF-only bottle/opponent classification is not reliable enough to authorize
  a push without front alignment/contact conditions. The sensors report range,
  not rule intent.
- A seam probe can distinguish many finite tape crossings from a persistent
  void, but no reflectance-only classifier can distinguish identical seam and
  void optical responses from one instantaneous sample.
- A color sensor can improve upright-bottle confirmation if calibrated on-site,
  but it is not a replacement for low ToF or edge sensing and is weaker on a
  fallen bottle.
- Two motors are preferable to a third mechanism motor until a mechanical
  proof shows that an active mechanism improves a clean front push without
  creating side-contact or size/weight risk.

### Unresolved assumptions requiring operator confirmation

- Exact ESP32-S3 module/dev-board variant, flash/PSRAM wiring, and exposed GPIOs.
- Existing motor-driver type, enable/standby pins, PWM polarity, stall current,
  and measured braking response.
- Exact QRE1113 item: raw four-pin device, analog module, or digital comparator
  module; output polarity and onboard LED resistor are unknown.
- Exact ToF carrier/module variant, pull-up population, regulator, and whether
  its XSHUT pin is actually exposed.
- Actual chassis dimensions, drive-wheel contact line, front-face geometry,
  sensor bracket space, mass, battery, and ground clearance.
- Tape width/material and whether seam readings are separable from true void.
- Whether front contact switches or a color sensor will be installed.

## Verification boundary

No repository implementation code was added for this design package. Host-side
source extraction and repository inspection do not prove wiring, sensor output,
motor behavior, brownout immunity, edge stopping, intentionality, or match
success. Those claims remain gated on the operator-run Phase 4 milestones.

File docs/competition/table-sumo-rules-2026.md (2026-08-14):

# 2026 Table-Sumo Competition Rules

Revision: `2026 Rev.0`

This is a neutral project reference transcribed from the attached 2026 rules
document. The document name and organizer branding are intentionally omitted.
The live rules publication and the referee committee's decisions control if a
later revision or event-day announcement differs from this reference.

## 1. Event objective

A round is won by either:

1. Finding and intentionally pushing a 2 L water bottle containing about 1 L
   of water off the arena; or
2. Being the last robot remaining on the arena.

After either condition is reached, the winning robot must remain on the arena
for at least 3 seconds. If the robot that pushed the bottle falls off before
3 seconds, the last-robot-standing rule is applied. If the other robot also
fails to remain on the arena for 3 seconds, the round is a draw.

## 2. Divisions and teams

| Division | Participant age | Kit and controller limits |
| --- | --- | --- |
| Junior | 7-12 years old | The listed educational robot kits are permitted; at most 1 controller. |
| Senior | 13-19 years old, including secondary and post-secondary students | Any brand or DIY equipment; at most 2 controllers. |

Age is calculated as of 31 July 2025. Every team must have one responsible
teacher, instructor, or coach. A team may have at most two participants.

## 3. Arena and bottle

- The arena uses rounded-corner fire-resistant wooden boards with a white or
  light-gray laminate surface.
- Each board is 75 cm x 182 cm (30 in x 72 in). The actual surface color is
  announced on the event day.
- The junior division uses a board arrangement similar to the single-board
  example.
- The senior division uses an unknown board arrangement. Two boards may be
  joined with tape in an offset layout. The tape color and material are
  announced during the inspection period.
- The boards may be raised on supports of unknown height.
- The bottle can be placed at any point along the joint line in the senior
  arrangements.
- The bottle is wrapped in white paper and has a colored band. The band color
  and material are announced during the inspection period.
- The bottle is approximately 21.6 cm tall. The band is approximately 3.8 cm
  wide and its center is approximately 8 cm from the bottom. The bottle may be
  upright or lying on its side.

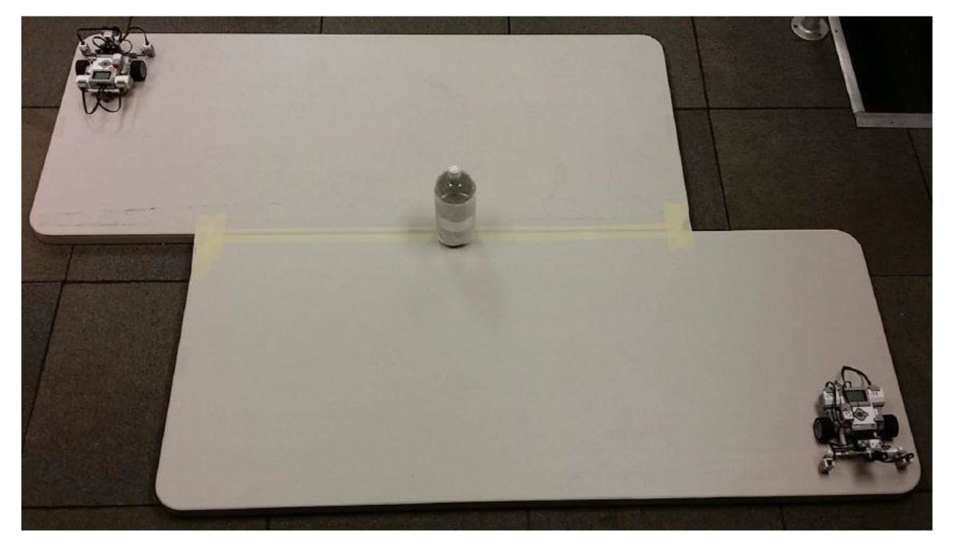
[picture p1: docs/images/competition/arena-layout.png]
Arena layout


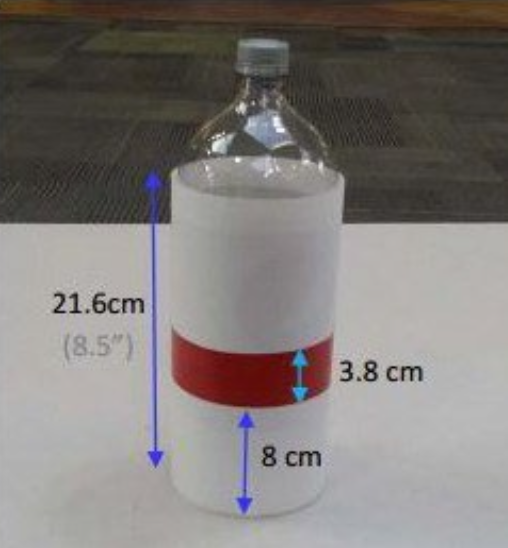
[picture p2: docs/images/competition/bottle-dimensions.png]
Bottle dimensions


## 4. Robot design requirements

| Requirement | Junior division | Senior division |
| --- | --- | --- |
| Robot kit | Listed educational kits | Any brand or DIY equipment |
| Controllers | At most 1 | At most 2 |
| Motors | Any type | At most 3 |
| Sensors | Unlimited except cameras or similar vision systems | Unrestricted |
| Static size | Diameter at most 30 cm; height at most 30 cm | Diameter at most 30 cm; height at most 30 cm |
| Expanded size | Expansion prohibited | Diameter at most 35 cm; height at most 35 cm |
| Weight | At most 1 kg | At most 1 kg |
| Ground clearance | At least 2 mm, except for movement structures and essential supports | At least 2 mm, except for movement structures and essential supports |
| Battery | Disposable or rechargeable battery output below 14 V | Disposable or rechargeable battery output below 14 V |
| Movement | Any, including walking, tracked, or wheeled | Any, including walking, tracked, or wheeled |
| Programming language | Any | Any |
| Operation | Fully autonomous; remote control may only start the robot | Fully autonomous; remote control may only start the robot |

The following are prohibited:

- Devices that fix the robot to the arena, including suction or vacuum devices.
- Sticky wheels.
- Sharp or pointed metal parts that can damage another robot.

All sensors must be harmless to people. A movement structure includes wheels,
casters, tracks, legs, and similar parts. A support is allowed only when it is
necessary for movement; removing it must make the robot unable to move, such as
by causing it to tip or leaving its tracks or wheels in the air.

Any battery may be used if its output voltage is below 14 V. Except for an
original kit battery, a rechargeable battery declaration must be submitted by
email at least two weeks before the event and accepted before use.

## 5. Inspection period

An inspection period occurs before the competition starts. The following are
announced during inspection:

- The starting position and orientation of each robot.
- The bottle band's actual color and material.
- The tape's actual color and material, if tape is present.

Teams should bring a computer, tools, and spare parts because lighting, floor
conditions, and board color may differ from the training environment. The team
must submit its robot to the inspection area. Staff attach a marker to the
front of the robot so referees can judge intentional bottle pushing.

If a violation is found, the team must return to the preparation area, correct
the robot, and submit it again. After inspection, the robot is stored in the
display area and the team receives a claim card. The card is exchanged to
retrieve the robot before each match and returned when the match ends. Failure
to complete inspection without a special reason results in disqualification.

## 6. Competition format and match procedure

- The competition has a group league followed by a knockout stage.
- The group draw places 2-3 teams in each group. Each team plays every other
  team in its group once.
- The top team from each group advances to the knockout draw. Group winners
  draw their knockout positions and play the opponents assigned to those
  positions. Winners continue through the bracket; after the final-four stage,
  the two losing teams play a third-place match and the two winning teams play
  the championship match.
- Each match is best of three rounds, with a 2-minute limit per round.
- A 30-second repair and adjustment period follows each round.

Before each round, teams place their robots at the announced positions and
orientations. When the referee starts the round, teams may start their robots
with a button or remote. From startup until the round ends:

- All participants must stay at least 1 m away from the arena.
- Participants must not touch the arena or anything on it.
- If a remote starts the robot, it must be placed on the floor near the team's
  feet immediately after the team moves 1 m away.
- A violation loses the round immediately.

If a team does not arrive at the assigned time, the opposing team wins the
match automatically. The winning team's score for that match is recorded as
zero for all rounds.

The robots then attempt to intentionally push the bottle off the arena or to
become the last robot remaining. After a round is decided, teams may adjust
their robots during the 30-second repair period. A robot that does not meet the
design requirements or is not placed correctly after the repair period loses
the round by forfeit. After the match, robots are returned to the display area.

### Draw conditions

Both teams receive one point when any of the following occurs:

- The second robot falls off within 3 seconds of the first robot.
- Neither robot starts within 30 seconds.
- Neither robot has made progress after 30 seconds.
- Neither robot has contacted the other after 30 seconds.
- The robots remain entangled and cannot recover movement for 30 seconds.
- No winner appears within the 2-minute round limit.

A robot is considered unable to continue when any part of it touches the ground
outside the arena. Once that ruling is made, returning to the arena does not
cancel it. A part that completely separates from the robot body and controller
is no longer considered part of the robot; its falling off does not create a
robot-fall ruling. A violation found during a match results in
disqualification.

## 7. Intentional bottle-push ruling

The bottle may be upright or lying on its side.

- **Intentional:** only one robot maintains continuous contact with the bottle
  using its marked front face until the bottle leaves the arena.
- **Unintentional:** one robot uses a side or rear face, or it makes front
  contact and then the bottle falls later, such as during a spin. The match
  continues as a one-on-one sumo match.
- **Unable to determine:** both robots maintain front contact with the bottle,
  or one robot maintains front contact while the other robot continuously
  contacts the pushing robot and contributes to the fall.

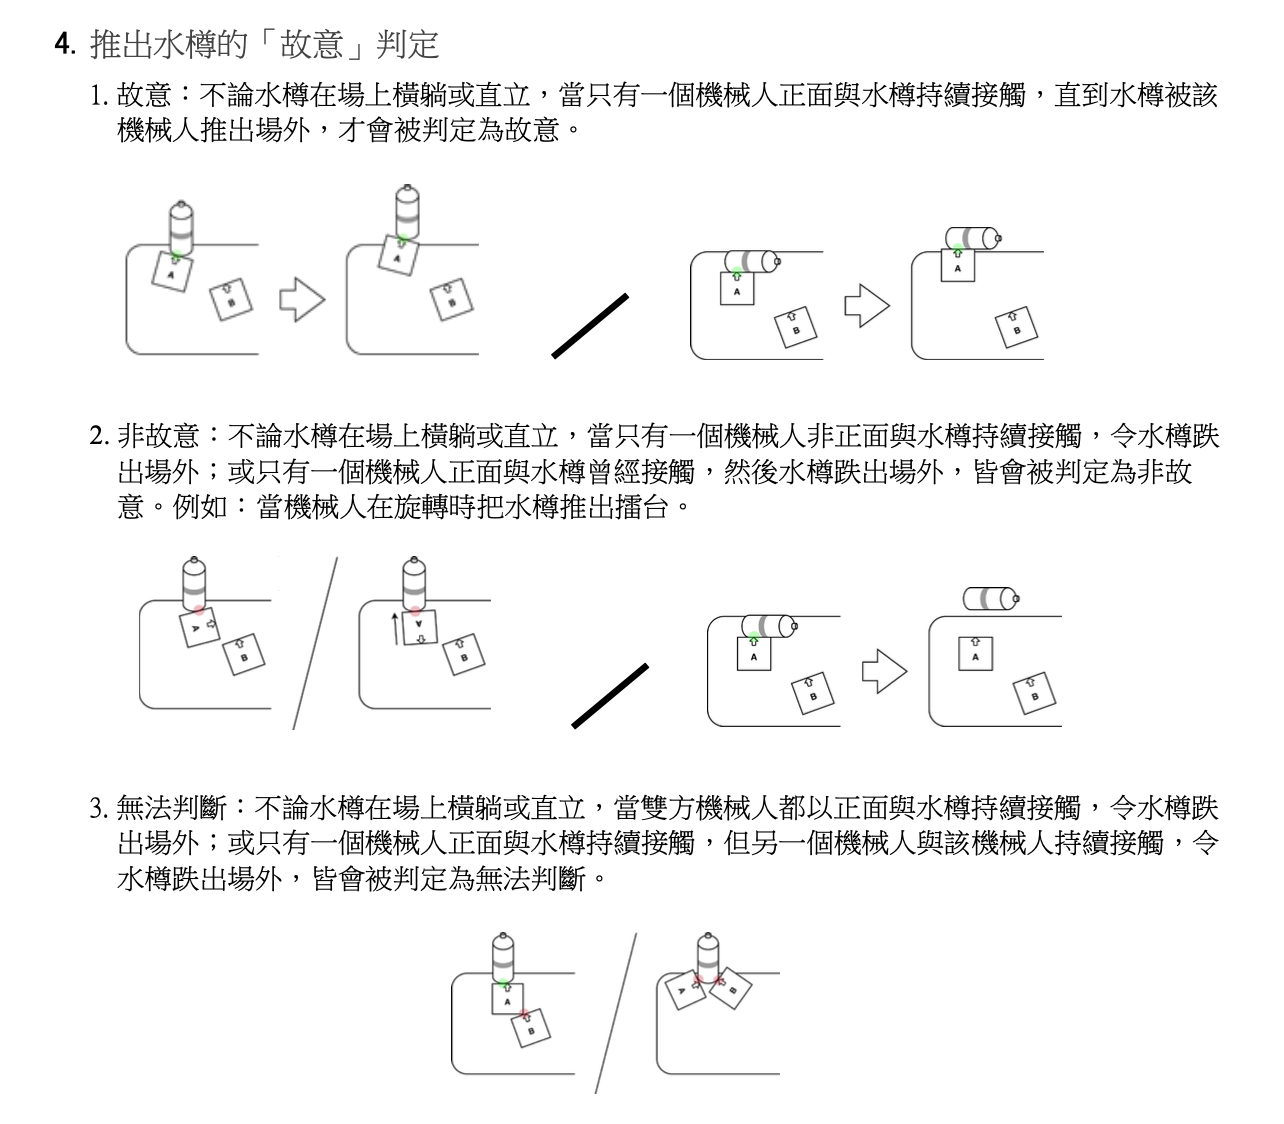
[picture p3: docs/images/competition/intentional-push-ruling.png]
Intentional-push ruling examples


## 8. Venue and disputes

- Standard local power outlets are provided. Teams must bring voltage or
  frequency converters and sufficiently long extension cords when needed.
- Lighting is ordinary venue lighting and may change due to sunlight, flashes,
  or other event lights. Teams have calibration time before the competition.
- The arena is installed on the floor. The organizers try to keep it flat, but
  wrinkles or unevenness may occur.
- Unspecified matters are decided by the referee committee at the venue.
- The referee committee has final authority over cases not covered by these
  rules and over the competition as a whole.
- Photos or videos taken by other people are not accepted as appeal evidence.

## Appendix: board arrangement references

The attached rules document illustrates one junior arrangement and two senior
arrangements. In the senior arrangements, the bottle may be placed at any
point along the indicated joint line. The exact arrangement, tape, bottle band,
and starting position are announced during inspection. The appendix also
includes a robot-size measuring reference.

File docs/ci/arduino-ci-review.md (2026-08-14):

# Arduino CI Review Record

Date: 2026-08-14

## Scope

This review covers the project-specific Arduino CI skill, the all-firmware
validator, the pinned candidate sensor-library install step, the local Git
hooks, and the project instructions used for future BottleSumo firmware work.

## Gate results

| Gate | Result | Evidence |
| --- | --- | --- |
| Firmware compilation | Pass | `./scripts/validate-firmware.sh` compiled 1 sketch for `esp32:esp32:esp32s3-octal:FlashSize=32M` with Arduino CLI 1.4.1 and Arduino-ESP32 3.3.8. |
| Library manifest | Pass | `ci/arduino-libraries.txt` contains the seven pinned candidate packages; the workflow installs it before validation. |
| Local hook safety | Pass | `.githooks/pre-commit` invokes the validator for firmware/build inputs; `.githooks/pre-push` rejects `refs/heads/main`. |
| Loop state hygiene | Pass | `.gitignore` ignores `loop-state.json` and `experiment-ledger.jsonl` at any repository depth. |
| Documentation and structure | Pass | `git diff --check`, workflow contract checks, and local Markdown path checks completed before commit. |

## Residual risk

Compilation does not prove GPIO electrical levels, motor direction, FG pulse
polarity, sensor readings, wiring, or powered-robot safety. Human review and
merge into `main` remain required.

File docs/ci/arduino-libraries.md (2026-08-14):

# Arduino sensor library matrix

The GitHub Actions workflow installs these pinned candidate libraries before it
compiles every Arduino sketch under `firmware/`. The current movement sketch
only includes `Arduino.h`; the sensor libraries are installed now so future
firmware changes have a known CI dependency set.

Arduino CLI resolves a library after a sketch includes a matching header, but a
fresh GitHub runner does not automatically download an arbitrary missing library
from the registry. The workflow therefore installs this explicit manifest:
`ci/arduino-libraries.txt`.

| Sensor | Arduino CLI package | Author | ROI / multizone | Project use |
| --- | --- | --- | --- | --- |
| VL53L5CX | `SparkFun VL53L5CX Arduino Library@1.0.3` | SparkFun | Full 4x4/8x8 | Primary multizone candidate |
| VL53L0X | `Adafruit_VL53L0X@1.2.5` | Adafruit | Single-zone | Primary full ST API wrapper candidate |
| VL53L0X | `VL53L0X@1.3.1` | Pololu | Single-zone | Lightweight yes/no proximity candidate |
| MPU-6050 | `Adafruit MPU6050@2.2.9` | Adafruit | Not applicable | Primary unified IMU candidate |
| VL53L4CD | `STM32duino VL53L4CD@1.0.5` | STMicroelectronics | Single-zone | Single-zone ToF candidate |
| VL53L1X | `Adafruit VL53L1X@3.1.2` | Adafruit | ROI-capable API | Primary ROI candidate |
| VL53L1X | `VL53L1X@1.3.1` | Pololu | No ROI | Smallest/simple API candidate |

The package name is the Arduino Library Manager name, which can differ from a
human product name. `arduino-cli lib install` also installs dependencies declared
by each package. Do not assume that installing alternatives selects one for the
firmware; choose the intended include/API deliberately and document that choice
in the firmware and board references.

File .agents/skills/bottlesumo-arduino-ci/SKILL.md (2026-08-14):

---
name: bottlesumo-arduino-ci
description: Validate every BottleSumo firmware-program change and build, inspect, or update the GitHub Actions Arduino CLI workflow for the ESP32-S3-DEVKITC-1-N32R16, including explicit sensor-library installation, toolchain pinning, README status reporting, hardware-reference updates, hooks, and safe feature-branch delivery. Use when changing any `firmware/**/*.ino`, `ci/arduino-libraries.txt`, `.github/workflows/arduino-cli-build.yml`, or related validation/documentation files.
---

# BottleSumo Arduino CI

## Contract

Treat `.github/workflows/arduino-cli-build.yml` as the executable source of truth.
Keep the following contract synchronized with the workflow and the linked project
references:

- Board: `ESP32-S3-DEVKITC-1-N32R16`
- FQBN: `esp32:esp32:esp32s3-octal:FlashSize=32M`
- Arduino CLI: `1.4.1`
- Arduino-ESP32 core: `3.3.8`
- Firmware programs: every Arduino sketch (`*.ino`) under `firmware/`
- Sensor manifest: `ci/arduino-libraries.txt`
- Triggers: `push`, `pull_request`, and `workflow_dispatch`

Use the project pinout reference for GPIO assignments, the motor reference for
FG/PWM facts, and the sensor library matrix for package choices. Do not infer
physical behavior from a successful compile.

## Workflow

1. Read `AGENTS.md`, this skill, the workflow, and the relevant files in `docs/`.
2. Preserve unrelated working-tree changes. Update from `origin/main`, then create
   a review branch named `codex/<short-topic>` for agent work or
   `human/<short-topic>` for human-authored work.
3. Change the smallest required surface. Pin new GitHub Actions and tool versions;
   do not add a floating core or action reference.
4. Install candidate libraries when reproducing CI or changing the manifest:

   ```bash
   ./scripts/install-arduino-libraries.sh
   ```

   Arduino CLI can resolve an installed library after seeing an `#include`, but
   it does not auto-download an arbitrary missing library from the registry.
   Keep future sensor choices in `ci/arduino-libraries.txt` instead of hiding
   installation commands in the workflow.

5. Run the local firmware gate when Arduino CLI and the ESP32 core are available:

   ```bash
   arduino-cli version
   arduino-cli core list
   ./scripts/validate-firmware.sh
   ```

   The validator discovers and compiles every `*.ino` under `firmware/`, so a
   new firmware program cannot silently avoid the build gate.

6. Install the versioned hooks for local guardrails:

   ```bash
   ./scripts/install-git-hooks.sh
   ```

   The pre-commit hook runs the validator for staged firmware, manifest, CI, or
   validator changes. The pre-push hook blocks direct pushes to `main` and
   guides contributors to `codex/*` or `human/*` review branches. Hooks
   complement, but do not replace, GitHub branch protection and Actions.

7. Run structural checks:

   ```bash
   git diff --check
   rg -n 'push:|pull_request:|workflow_dispatch:|esp32:esp32@3.3.8|esp32:esp32:esp32s3-octal:FlashSize=32M' \
     .github/workflows/arduino-cli-build.yml
   ```

   Resolve every local Markdown image/link after documentation changes. Confirm
   moved images in `docs/images/` exist and old flat paths are absent.

8. Review `git diff --stat`, `git diff --name-only`, and the staged diff. Keep build
   output, caches, secrets, and unrelated user files out of the commit.
9. Push the review branch only. Never push this project change directly to `main`,
   force-push, or merge it. A human must review and merge the branch into `main`.

## Hardware Boundary

The project currently assigns motor FG inputs to GPIO9 and GPIO12 and records 9
square-wave FG pulses per motor revolution. Treat motor wire identity, FG voltage,
pull-up requirements, shaft reference, direction polarity, PWM behavior, and
sensor readings as unverified until measured on the actual hardware.

The current movement sketch has a documented pin mismatch with the v2 schematic.
Do not approve a powered motor test or claim hardware readiness solely because CI
compiles. Update `docs/hardware/esp32-s3-devkitc-1-n32r16-pinout.md` when the audited
firmware mapping changes.

## Project References

- Workflow: `.github/workflows/arduino-cli-build.yml`
- Library manifest: `ci/arduino-libraries.txt`
- Firmware validator: `scripts/validate-firmware.sh`
- Hook installer: `scripts/install-git-hooks.sh`
- Documentation hub: `docs/README.md`
- Sensor library matrix: `docs/ci/arduino-libraries.md`
- Project rules: `AGENTS.md`
- Board and signal map: `docs/hardware/esp32-s3-devkitc-1-n32r16-pinout.md`
- Motor and FG reference: `docs/hardware/motor-24gp-2430-reference.md`
- Competition rules: `docs/competition/table-sumo-rules-2026.md`
- User-facing CI result: `README.md`

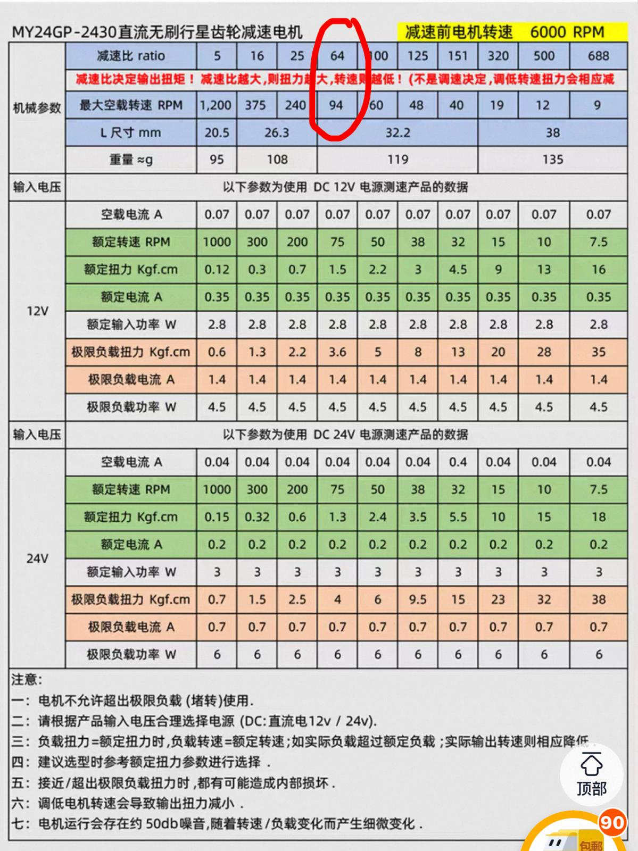
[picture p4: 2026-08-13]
docs/images/motor/motor-24gp-2430-64-to-1-specification.png

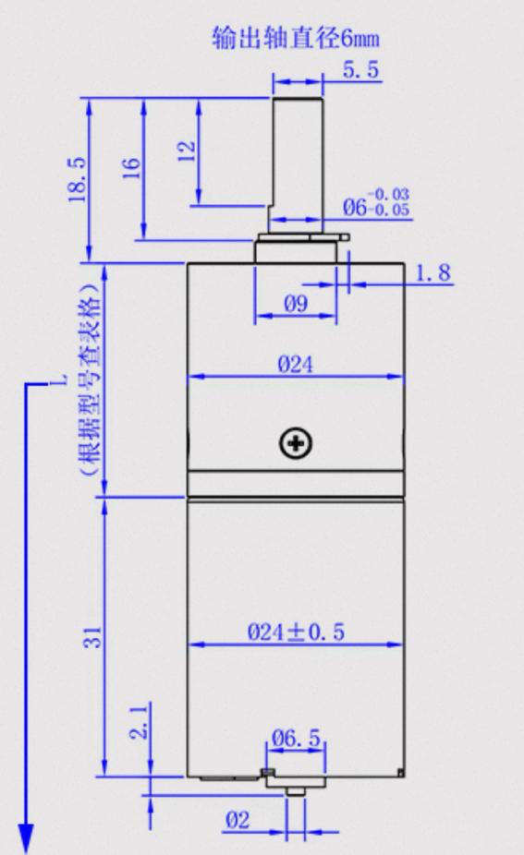
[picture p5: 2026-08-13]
docs/images/motor/motor-24gp-2430-wire-and-fg.png

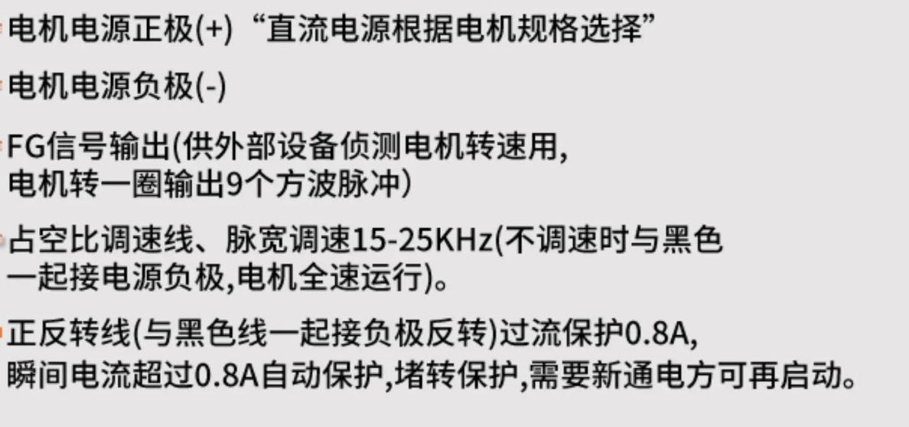
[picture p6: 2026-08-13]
docs/images/motor/motor-24gp-2430-fg-pulse-description.png

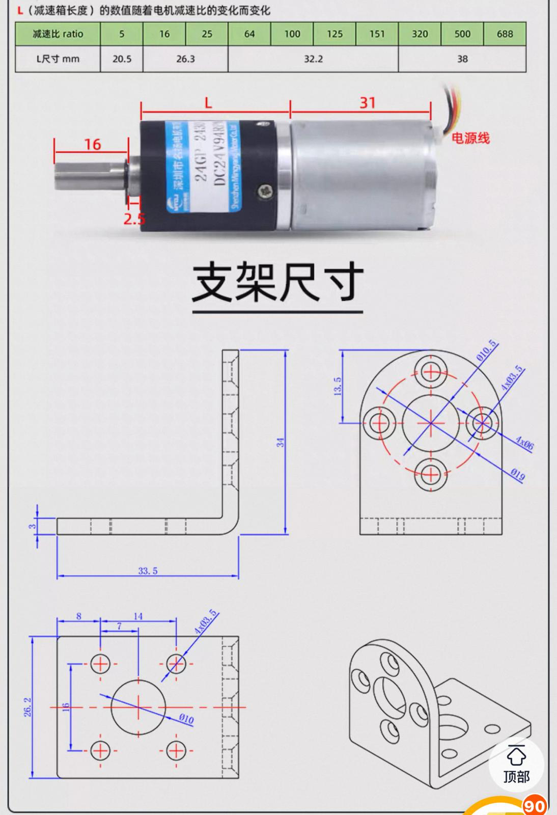
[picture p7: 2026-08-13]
docs/images/motor/motor-24gp-2430-dimensions.png

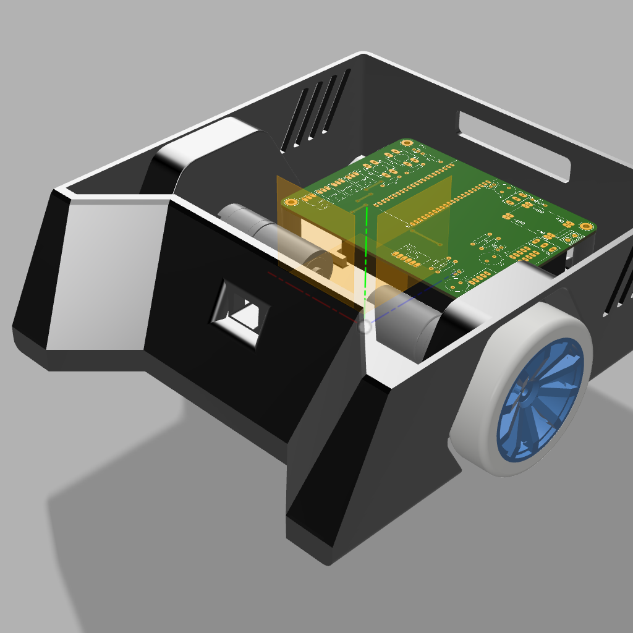
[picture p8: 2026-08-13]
3D model/v1/Bottlesumo_V1.png

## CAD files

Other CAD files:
3D model/Component 3D Model/E326S-Battery.f3d
3D model/Component 3D Model/High Grip Wheel.f3d
3D model/Component 3D Model/MOTOR STAND 24GP.f3d
3D model/Component 3D Model/Motor 24GP.f3d
3D model/Component 3D Model/QRE1113 sensor module.f3d
3D model/Component 3D Model/VL53L0X_TOF.f3d

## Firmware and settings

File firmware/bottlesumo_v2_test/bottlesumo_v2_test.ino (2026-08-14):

/*
 * BottleSumo v2 - ESP32-S3-DevKitC-1 electrical/function test
 * Target: ESP32-S3-WROOM-2
 *
 * Required Arduino IDE library:
 *   VL53L0X by Pololu
 *
 * Safety:
 *   - All motor outputs start at PWM=0.
 *   - The motor test is never started automatically. Send 'm', then 'y'.
 *   - Remove the mechanical load / lift the wheels before running the motor
 *     test. Keep the motor-driver 12 V side away from ESP32 GPIOs.
 *   - GPIO18 is the VL53L0X GPIO/interrupt input. XSHUT is fixed to 3V3 in
 *     the schematic, so this sketch does not drive XSHUT.
 */

#include <Arduino.h>
#include <Wire.h>
#include <VL53L0X.h>

// ------------------------- Pin map from bottlesumo_v2_doc.txt ----------------
constexpr uint8_t QRE1_PIN = 1;
constexpr uint8_t QRE2_PIN = 2;
constexpr uint8_t QRE3_PIN = 4;
constexpr uint8_t QRE4_PIN = 5;

constexpr uint8_t MOTOR1_SIGNAL_PIN = 9;
constexpr uint8_t MOTOR1_PWM_PIN = 10;
constexpr uint8_t MOTOR1_DIR_PIN = 11;
constexpr uint8_t MOTOR2_SIGNAL_PIN = 12;
constexpr uint8_t MOTOR2_PWM_PIN = 13;
constexpr uint8_t MOTOR2_DIR_PIN = 14;

constexpr uint8_t I2C_SCL_PIN = 16;
constexpr uint8_t I2C_SDA_PIN = 17;
constexpr uint8_t VL53L0X_GPIO_PIN = 18;

constexpr uint8_t STATUS_LED_PIN = 40;
constexpr uint8_t BUTTON1_PIN = 41;
constexpr uint8_t BUTTON2_PIN = 42;

constexpr uint8_t QRE_PINS[] = {QRE1_PIN, QRE2_PIN, QRE3_PIN, QRE4_PIN};
constexpr uint8_t QRE_COUNT = sizeof(QRE_PINS) / sizeof(QRE_PINS[0]);

constexpr uint8_t TOF_I2C_ADDRESS = 0x29;
constexpr uint8_t PWM_MAX = 255;
constexpr uint8_t MOTOR_TEST_DUTY = 255;       // 25% of 8-bit PWM
constexpr uint32_t LIVE_REPORT_PERIOD_MS = 2000;

VL53L0X tof;
bool tofReady = false;
bool motorTestPending = false;
uint32_t lastLiveReportMs = 0;

volatile uint32_t motor1Edges = 0;
volatile uint32_t motor2Edges = 0;

void IRAM_ATTR motor1EdgeISR() {
  ++motor1Edges;
}

void IRAM_ATTR motor2EdgeISR() {
  ++motor2Edges;
}

void printHelp();
void scanI2C();
void initTof();
void printTofReading();
void printQreReadings();
void printButtonReadings();
void printMotorSignals(bool resetEdgeCounters);
void ledSelfTest();
void stopAllMotors();
void runMotorTest();

void setup() {
  Serial.begin(115200);

  // USB CDC may take a moment to enumerate on the ESP32-S3.
  const uint32_t serialWaitStart = millis();
  while (!Serial && (millis() - serialWaitStart < 3000)) {
    delay(10);
  }

  Serial.println();
  Serial.println(F("BottleSumo v2 - ESP32-S3 electrical/function test"));
  Serial.println(F("Target: ESP32-S3-WROOM-2 / ESP32-DevKitC-1"));
  Serial.println(F("Motor outputs are disabled at startup."));

  // QRE1113 modules: 3V3/GND/OUT. INPUT keeps the external circuit visible.
  for (uint8_t i = 0; i < QRE_COUNT; ++i) {
    pinMode(QRE_PINS[i], INPUT);
  }

  // Motor signal pins are inputs from the motor controller/feedback circuit.
  pinMode(MOTOR1_SIGNAL_PIN, INPUT);
  pinMode(MOTOR2_SIGNAL_PIN, INPUT);

  // PWM and DIR are logic-level outputs to the motor controller.
  pinMode(MOTOR1_PWM_PIN, OUTPUT);
  pinMode(MOTOR1_DIR_PIN, OUTPUT);
  pinMode(MOTOR2_PWM_PIN, OUTPUT);
  pinMode(MOTOR2_DIR_PIN, OUTPUT);
  stopAllMotors();

  // External pull-down resistors are present in the schematic.
  pinMode(BUTTON1_PIN, INPUT);
  pinMode(BUTTON2_PIN, INPUT);

  pinMode(STATUS_LED_PIN, OUTPUT);
  digitalWrite(STATUS_LED_PIN, LOW);

  // GPIO18 is the VL53L0X GPIO/interrupt line. XSHUT is hard-wired to 3V3.
  pinMode(VL53L0X_GPIO_PIN, INPUT);

  attachInterrupt(digitalPinToInterrupt(MOTOR1_SIGNAL_PIN), motor1EdgeISR, RISING);
  attachInterrupt(digitalPinToInterrupt(MOTOR2_SIGNAL_PIN), motor2EdgeISR, RISING);

  // Wire.begin() takes SDA first and SCL second.
  Wire.begin(I2C_SDA_PIN, I2C_SCL_PIN);
  Wire.setClock(400000);

  scanI2C();
  initTof();
  ledSelfTest();
  printQreReadings();
  printButtonReadings();
  printMotorSignals(false);
  printHelp();
}

void loop() {
  while (Serial.available() > 0) {
    const char command = static_cast<char>(Serial.read());
    if (command == '\r' || command == '\n' || command == ' ') {
      continue;
    }

    switch (command) {
      case '?':
        printHelp();
        break;
      case 'q':
        printQreReadings();
        break;
      case 'b':
        printButtonReadings();
        break;
      case 'i':
        scanI2C();
        printTofReading();
        break;
      case 't':
        printTofReading();
        break;
      case 's':
        printMotorSignals(true);
        break;
      case 'l':
        ledSelfTest();
        break;
      case 'm':
        motorTestPending = true;
        Serial.println(F("Motor test armed. Check the wheels are lifted, then send 'y'."));
        Serial.println(F("Send 'x' to cancel."));
        break;
      case 'y':
        if (motorTestPending) {
          runMotorTest();
        } else {
          Serial.println(F("No motor test is armed. Send 'm' first."));
        }
        break;
      case 'x':
        motorTestPending = false;
        stopAllMotors();
        Serial.println(F("Motor test cancelled; motor outputs stopped."));
        break;
      default:
        Serial.println(F("Unknown command. Send '?' for help."));
        break;
    }
  }

  if (millis() - lastLiveReportMs >= LIVE_REPORT_PERIOD_MS) {
    lastLiveReportMs = millis();
    Serial.printf("[LIVE] BTN1=%d BTN2=%d VL53_GPIO18=%d | ",
                  digitalRead(BUTTON1_PIN), digitalRead(BUTTON2_PIN),
                  digitalRead(VL53L0X_GPIO_PIN));
    printMotorSignals(false);
    printTofReading();
  }
}

void printHelp() {
  Serial.println();
  Serial.println(F("Commands (send in Serial Monitor at 115200 baud):"));
  Serial.println(F("  ?  show this help"));
  Serial.println(F("  q  read all QRE1113 inputs as digital + ADC"));
  Serial.println(F("  b  read BUTTON1/2; HIGH means pressed"));
  Serial.println(F("  i  scan I2C and read VL53L0X"));
  Serial.println(F("  t  read one VL53L0X distance"));
  Serial.println(F("  s  show motor signal levels and edge counters"));
  Serial.println(F("  l  blink GPIO40 status LED"));
  Serial.println(F("  m  arm the motor test; y starts it, x cancels/stops"));
  Serial.println();
}

void scanI2C() {
  uint8_t deviceCount = 0;
  Serial.println(F("I2C scan on SDA=GPIO17, SCL=GPIO16:"));

  for (uint8_t address = 1; address < 127; ++address) {
    Wire.beginTransmission(address);
    const uint8_t error = Wire.endTransmission();
    if (error == 0) {
      Serial.printf("  found 0x%02X", address);
      if (address == TOF_I2C_ADDRESS) {
        Serial.print(F(" (expected VL53L0X)"));
      }
      Serial.println();
      ++deviceCount;
    }
  }

  if (deviceCount == 0) {
    Serial.println(F("  no I2C device found; check 3V3, GND, SDA, and SCL."));
  } else {
    Serial.printf("  total devices: %u\n", deviceCount);
  }
}

void initTof() {
  tof.setTimeout(250);

  Wire.beginTransmission(TOF_I2C_ADDRESS);
  const uint8_t addressCheck = Wire.endTransmission();
  if (addressCheck != 0) {
    Serial.println(F("VL53L0X not detected at 0x29; distance test unavailable."));
    tofReady = false;
    return;
  }

  if (!tof.init()) {
    Serial.println(F("VL53L0X init failed; check module power and I2C wiring."));
    tofReady = false;
    return;
  }

  // A moderate timing budget gives a stable test reading without being slow.
  tof.setMeasurementTimingBudget(33000);
  tof.startContinuous(100);
  tofReady = true;
  Serial.println(F("VL53L0X initialized; continuous ranging started."));
}

void printTofReading() {
  if (!tofReady) {
    Serial.println(F("VL53L0X: NOT READY"));
    return;
  }

  const uint16_t distanceMm = tof.readRangeContinuousMillimeters();
  if (tof.timeoutOccurred()) {
    Serial.println(F("VL53L0X: TIMEOUT"));
    return;
  }

  Serial.printf("VL53L0X: %u mm, GPIO18=%d\n", distanceMm,
                digitalRead(VL53L0X_GPIO_PIN));
}

void printQreReadings() {
  Serial.println(F("QRE1113 readings (digital HIGH/LOW plus raw ADC 0..4095):"));
  for (uint8_t i = 0; i < QRE_COUNT; ++i) {
    const int digitalValue = digitalRead(QRE_PINS[i]);
    const int analogValue = analogRead(QRE_PINS[i]);
    Serial.printf("  QRE%u GPIO%u: digital=%d, analog=%d\n", i + 1,
                  QRE_PINS[i], digitalValue, analogValue);
  }
}

void printButtonReadings() {
  Serial.printf("Buttons: BUTTON1 GPIO41=%s, BUTTON2 GPIO42=%s (HIGH=pressed)\n",
                digitalRead(BUTTON1_PIN) ? "PRESSED" : "released",
                digitalRead(BUTTON2_PIN) ? "PRESSED" : "released");
}

void printMotorSignals(bool resetEdgeCounters) {
  if (resetEdgeCounters) {
    noInterrupts();
    motor1Edges = 0;
    motor2Edges = 0;
    interrupts();
  }

  uint32_t motor1EdgeSnapshot;
  uint32_t motor2EdgeSnapshot;
  noInterrupts();
  motor1EdgeSnapshot = motor1Edges;
  motor2EdgeSnapshot = motor2Edges;
  interrupts();

  Serial.printf("Motor signals: SIG1 GPIO9=%d edges=%lu, SIG2 GPIO12=%d edges=%lu\n",
                digitalRead(MOTOR1_SIGNAL_PIN),
                static_cast<unsigned long>(motor1EdgeSnapshot),
                digitalRead(MOTOR2_SIGNAL_PIN),
                static_cast<unsigned long>(motor2EdgeSnapshot));
}

void ledSelfTest() {
  Serial.println(F("LED test on GPIO40..."));
  for (uint8_t i = 0; i < 3; ++i) {
    digitalWrite(STATUS_LED_PIN, HIGH);
    delay(150);
    digitalWrite(STATUS_LED_PIN, LOW);
    delay(150);
  }
}

void stopAllMotors() {
  analogWrite(MOTOR1_PWM_PIN, 0);
  analogWrite(MOTOR2_PWM_PIN, 0);
  digitalWrite(MOTOR1_DIR_PIN, LOW);
  digitalWrite(MOTOR2_DIR_PIN, LOW);
}

void setMotor(uint8_t pwmPin, uint8_t dirPin, bool forward, uint8_t duty) {
  digitalWrite(dirPin, forward ? HIGH : LOW);
  analogWrite(pwmPin, duty);
  Serial.printf("  GPIO%u DIR=%d, GPIO%u PWM duty=%u, output level=%d\n",
                dirPin, forward ? HIGH : LOW, pwmPin, duty,
                digitalRead(pwmPin));
}

bool runMotorPhase(const __FlashStringHelper* label, uint8_t pwmPin,
                   uint8_t dirPin, bool forward, uint32_t durationMs) {
  Serial.print(label);
  Serial.println(F("..."));
  noInterrupts();
  motor1Edges = 0;
  motor2Edges = 0;
  interrupts();

  setMotor(pwmPin, dirPin, forward, MOTOR_TEST_DUTY);
  const uint32_t phaseStart = millis();
  while (millis() - phaseStart < durationMs) {
    if (Serial.available() > 0 && Serial.read() == 'x') {
      stopAllMotors();
      Serial.println(F("Emergency stop received."));
      return false;
    }
    delay(5);
  }

  stopAllMotors();
  delay(250);
  printMotorSignals(false);
  return true;
}

void runMotorTest() {
  motorTestPending = false;
  Serial.println(F("Motor test starting: 25% PWM, 5000 ms per direction."));
  Serial.println(F("Send 'x' at any time for an emergency stop."));

  if (!runMotorPhase(F("Motor 1 forward"), MOTOR1_PWM_PIN, MOTOR1_DIR_PIN,
                     true, 5000)) {
    return;
  }
  if (!runMotorPhase(F("Motor 1 reverse"), MOTOR1_PWM_PIN, MOTOR1_DIR_PIN,
                     false, 5000)) {
    return;
  }
  if (!runMotorPhase(F("Motor 2 forward"), MOTOR2_PWM_PIN, MOTOR2_DIR_PIN,
                     true, 5000)) {
    return;
  }
  if (!runMotorPhase(F("Motor 2 reverse"), MOTOR2_PWM_PIN, MOTOR2_DIR_PIN,
                     false, 5000)) {
    return;
  }

  stopAllMotors();
  Serial.println(F("Motor test complete; all motor outputs stopped."));
}

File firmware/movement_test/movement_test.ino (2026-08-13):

#include <Arduino.h>

#define LPWM 1
#define LDIR 2
#define RPWM 15
#define RDIR 14
#define LED1 17

const uint8_t Loffset = 6;

void forward(uint8_t speed){
  analogWrite(LPWM,(speed - Loffset));
  analogWrite(RPWM,speed);
  digitalWrite(LDIR, 1);
  digitalWrite(RDIR, 0);
}

void backward(uint8_t speed){
  analogWrite(LPWM,(speed - Loffset));
  analogWrite(RPWM,speed);
  digitalWrite(LDIR, 0);
  digitalWrite(RDIR, 1);
}

void Right_ward(uint8_t speed){
  analogWrite(LPWM,(speed - Loffset));
  analogWrite(RPWM,speed);
  digitalWrite(LDIR, 1);
  digitalWrite(RDIR, 1);
}

void Left_ward(uint8_t speed){
  analogWrite(LPWM,(speed - Loffset));
  analogWrite(RPWM,speed);
  digitalWrite(LDIR, 0);
  digitalWrite(RDIR, 0);
}

void stop(){
  digitalWrite(LPWM, LOW);
  digitalWrite(RPWM, LOW);
}

bool hasRun = false;

void setup() {
    Serial.begin(115200);
    pinMode(LPWM, OUTPUT);
    pinMode(LDIR, OUTPUT);
    pinMode(RPWM, OUTPUT);
    pinMode(RDIR, OUTPUT);
    pinMode(LED1, OUTPUT);
    digitalWrite(LED1, HIGH);

}

void loop() {
  Serial.println("Car is moving forward");
  forward(255);
  delay(1000);
  Serial.println("Car is stopping");
  stop();
  delay(2000);
  Serial.println("Car is moving leftward");
  Left_ward(255);
  delay(1000);
  Serial.println("Car is stopping");
  stop();
  delay(2000);
  Serial.println("Car is moving rightward");
  Right_ward(255);
  delay(1000);
  Serial.println("Car is stopping");
  stop();
  delay(2000);
  Serial.println("Car is moving backward");
  backward(255);
  delay(1000);
  Serial.println("Car is stopping");
  stop();
  delay(2000);
}

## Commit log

2026-08-13 Add BottleSumo hardware designs and movement firmware
    [E326S-Battery.f3d, High Grip Wheel.f3d, MOTOR STAND 24GP.f3d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]
2026-08-13 Add ESP32-S3 Arduino CI and hardware references
    Compile the movement sketch on every push and pull request for the ESP32-S3-DEVKITC-1-N32R16 target. Add reusable board, motor, and competition-rule documentation, rename the rules images, and ignore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
2026-08-14 Add project CI skill and branch safety guidance
    Document the ESP32-S3 Arduino CLI build contract as a reusable project-local skill and add project-specific agent guidance. Require feature-branch pushes and human merges while preserving the existin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
2026-08-14 bottle sumo test code v1
    version 1 pcb test code
2026-08-14 ci: validate all firmware and pin sensor libraries
    Build every firmware sketch, install the versioned candidate sensor libraries, add local hooks, and document the project-wide validation contract.
2026-08-14 Add table-sumo design and evidence docs
    This adds the Phase 1-3 Table-Sumo design review and the provenance ledger for the proposed sensor and strategy architecture. The documents cover ToF/QRE layout trade-offs, electrical pin and power p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
2026-08-14 docs: organize references and add 2026 rules
    Group documentation and images by purpose, add a neutral competition rules transcription, preserve the LED GPIO reference, and document codex or human review branches.
2026-10-14 feat: add BottleSumo competition firmware, tools, and CAD artifacts
2026-11-12 Add Arduino IDE firmware port with web tuning and OTA
    Port firmware/bottlesumo_idf to Arduino IDE for the ESP32-S3 DevKitC-1
    N16R8, keeping the IDF pinout and the 84-byte telemetry layout so
    tools/bottlesumo_debug still parses the UDP stream.
    - explicit State enum, single change() per transition, 64-entry history
    ring buffer mirrored to the web UI
    - QRE1113 self-calibration (floor/void clusters, auto polarity, 300-count
    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
2026-11-12 Add opening script, carry arc and edge robustness to the Arduino firmware
    Three changes to the competition behaviour, all runtime-tunable from the web
    UI and persisted in NVS:
    - Opening run: straight, ~60 deg pivot, straight, timed from the start delay.
    A centre ToF reading inside openingAbortMm hands over early, so the script
    cannot drive past the bottle. Any confirmed edge still escapes.
    - Carry: after contact, an alternating differential arcs the robot and drags
    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
2026-11-12 Align firmware pin map with the v2 Eagle schematic
    Use GPIO48 and GPIO47 together for the status LEDs, drop the unrouted GPIO18 ToF interrupt input, and move the legacy movement sketch to PWM1/PWM2/DIR1/DIR2. Update the active and historical pinout d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
